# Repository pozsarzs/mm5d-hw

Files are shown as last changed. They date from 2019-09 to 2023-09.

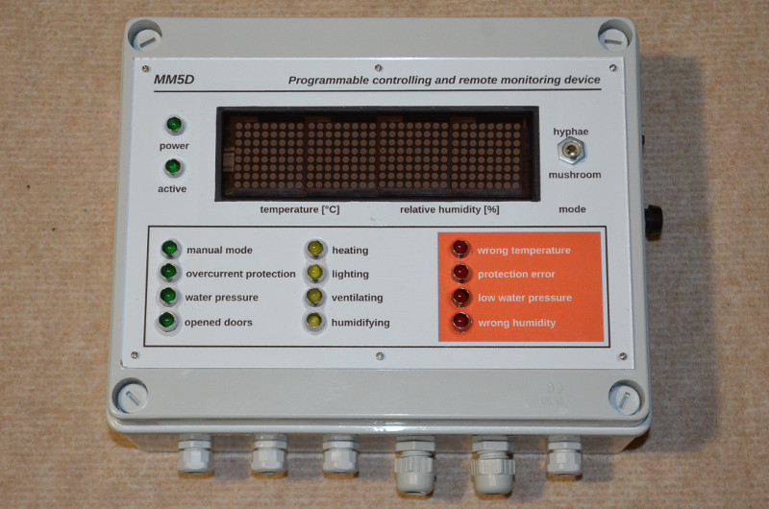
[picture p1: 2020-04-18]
pictures/mm5d.jpg

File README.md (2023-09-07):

**MM5D * Growing house controlling and remote monitoring device**  
Copyright (C) 2019-2020 Pozsár Zsolt <pozsarzs@gmail.com>  
Homepage: <http://www.pozsarzs.hu>  
GitHub: <https://github.com/pozsarzs/mm5d-hw>

**Documentation**

- version:             4.0
- language:            en, hu
- licence:             CC-BY-NC-4.0

**Hardware**

 - version:            v191101

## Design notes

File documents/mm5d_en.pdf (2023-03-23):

## MM5D growing house controlling and remote monitoring unit

### Technical manual

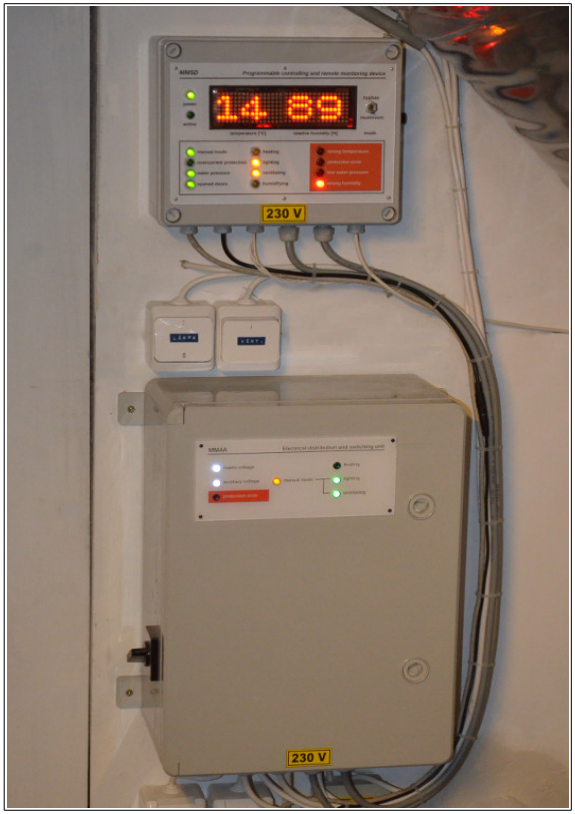
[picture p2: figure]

Hardware version: v191101
Software version: v0.6
Technical manual version: v4.0 Issue date: 2023. 03. 23.
Draw number: 59/5/1-1

## CC-BY-NC-4.0

Content

Titles: | MM5D growing house controlling and remote monitoring unit Rev.: 191101 Pages: | 2/34
Technical manual
Name: Pozsár Zsolt | Date: 2023. 03. 23.

## I. Hardware

Titles: | MM5D growing house controlling and remote monitoring unit Rev.: 191101 Pages: | 3/34

The device - cooperates with MM4A distribution and switching unit - is capable of measuring, controlling and monitoring the characteristics of a growing site.

### 1. Technical data

Supply voltage: | 5V DC (with 230 V AC/5 V DC power supply)
Supply current: | max. 2.5 A
Isolation class: | Class I
Mechanical size: | 240 x 190 x 90 mm
IP protection: | IP 54
Mass of cover: | termoplast (ABS)
Communication: | Ethernet (RJ45),
| Wireless LAN,
| TTL 3.3V serial port
Administration: | SSH,
| serial console
Input:
sign | function | note
IN 1 | MM4A manual operation mode | manual mode: level L
IN 2 | MM4A overcurrent error | error: level L
IN 3 | check water pressure | good: level L
IN 4 | check state of doors | closed: level L

Outputs:
sign | function | note
OUT 1 | heater control output to MM4A
OUT 2 | lighting control output to MM4A
OUT 3 | ventilator control output to MM4A
OUT 4 | humidifier control output

Error sign lamps:
sign | function | note
ERR 1 | temperature is out of good range
ERR 2 | MM4A overcurrent error
ERR 3 | water pressure is too low
ERR 4 | humidity is out of good range
Titles: | MM5D growing house controlling and remote monitoring unit Rev.: 191101 Pages: | 4/34

Status outputs:
sign | function | note
OUT 5 | signal tower light - green | normal operation
OUT 6 | signal tower light - yellow | normal operation with warning
OUT 7 | signal tower light - red | error
OUT 8 | not used/spare

Measured characteristics:
name | range | resolution | accuracy | note
temperature | -40...+80 °C | 0,1 °C | < ±0,5 °C
humidity | 0-100% RH | 0,1 % RH | ±2 % RH

### 2. General description

The device is based on a Raspberry Pi 3 B + microcomputer with Raspbian operating system and includes software needed to operate the unit. Your computer does not have a graphics system installed.

You do not need to connect a keyboard and monitor to set up and operate the device., you can see input and output status, error indications, measured values and system messages (see 3.) on the LEDs and the matrix LED display. You can acces to set up device via local area network with SSH or serial console. The measured data can be checked with a web browser.

The inputs are TTL level inputs with pull-up resistance and the active state is level "L". The inputs are protected against overvoltage and reverse polarity input voltage.

DHT 11, DHT 22 or AM2302 T / RH sensors can be connected to the unit.

The device has eight switching relay contact outputs with a load capacity of up to 250 V AC or up to 30 V DC 10 A, but an external relay or contactor is recommended to protect the printed circuit. Consumer circuits must always be provided with overcurrent protection. The relays can be disabled with the key switch on the right.

### 3. System messages on display

In addition to the measured values, the system may display system messages consisting of the following combination of letters and numbers:

Titles: | MM5D growing house controlling and remote monitoring unit Rev.: 191101 Pages: | 5/34

a) Debug codes

You can see these on display if verbose debug logging enabled.
D #00 | Configuration is loaded.
D #01 | Environment characteristics is loaded.
D #02 | Starting program as daemon.
D #03 | Initializing GPIO ports.
D #04 | Checking override file.
D #05 | Get external temperature from internet.
D #06 | Measuring T/RH.
D #07 | Measure is done.
D #08 | Reading input ports.
D #09 | Check values and set outputs.
D #10 | Writing output ports.
D #11 | Auto off enabled at 4th output port.
D #12 | Creating lockfile.
D #13 | Writing data to log.
D #14 | Removing lockfile.
D #15 | Waiting 10 s.
b) Warning codes
W #01 | Cannot get external temperature from internet.
W #02 | Measured values are bad!
W #51 | MM4A in manual operation mode.
W #52 | Doors/windows are opened.
c) Error codes
E #01 | Cannot open main configuration file.
E #02 | Cannot open environment characteristic configuration file.
E #03 | Cannot create/remove lockfile.
E #04 | Cannot write logfile.
E #51 | Temperature in growing house is out of range.
E #52 | MM4A overcurrent protection error.
E #53 | Water pressure is too low.
E #54 | Relative humidity in growing house is out of range.
Titles: | MM5D growing house controlling and remote monitoring unit Rev.: 191101 Pages: | 6/34

### 4. Signal tower light states

green | normal operation
green+yellow | MM4A is in manual operation mode
one of the doors is open

red

MM4A overcurrent error
water pressure is too low

### 5. Schematic and PCB draws

The wiring diagrams of the device is shown in Annex 1-3, PCB draws are in Annex 5-10. You can download it as part of the complete documentation or in separate PDF, SVG and KiCAD formats from the developer/manufacturer's website. The Gerber files needed for production are included in the package.

### 6. Other draws and documents

Documentation package contents Drilling draws in PDF and DXF format and draw and frontpage in EMF, EPS, PDF, ODG and SVG format and wiring lists in TXT format.

### 7. Terms of use

Hardware documentation can be modified and/or redistributed under the Creativ Commons 4.0 Attribution Non-Commercial (CC-BY-NC-4.0) License. You can read the full (English) text of the license online. (Refer to Chapter III for references.)

### 8. Look of unit

a) Manuals and connectors
1. under supply voltage (green LED)
2. ACT signal light (green LED)
3. matrix display
4. operation mode switch
5. IN 1-4 active input signal light (green LED)
6. OUT 1-4 active output signal light (yellow LED)
7. ERR 1-4 signal light (red LED)
8. console connector (J2)
9. fuse of supply voltage (2,5 A F)
10. disable output relays key switch
Titles: | MM5D growing house controlling and remote monitoring unit Rev.: 191101 Pages: | 7/34

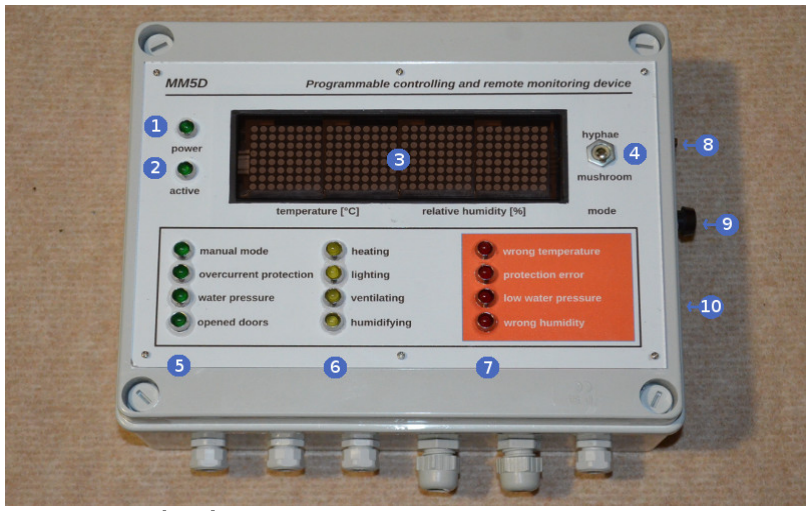
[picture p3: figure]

b) Internal construction
1. Raspberry Pi (U1)
2. GPIO port expansion module (U2)
3. matrix display module (U3)
4. module of LEDs (U4)
5. input module (U5)
6. output module (U6)
7. output module (U7)
8. supply voltage filter and speaker driver circuit
9. speaker
10. power voltage connector (J1)
11. inputs connector (J501)
12. sensor connector (J502)
13. OUT 1-4 connector
14. OUT 5-8 connector
15. screw hole
Titles: | MM5D growing house controlling and remote monitoring unit Rev.: 191101 Pages: | 8/34

Figure 1: Manuals and connectors

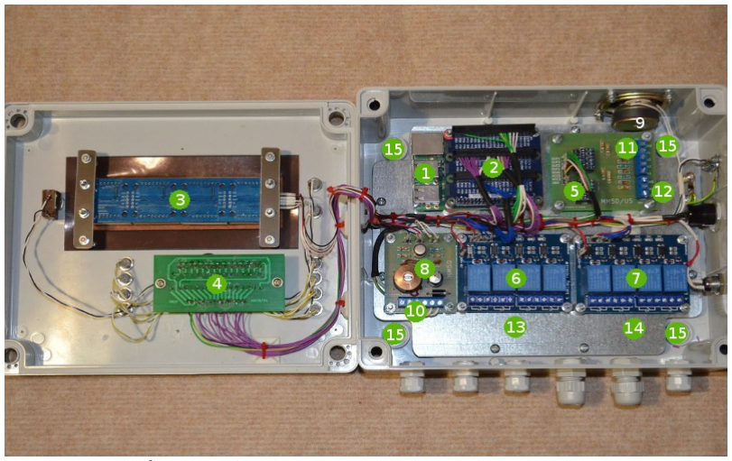
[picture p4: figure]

c) Pinout of connectors
module | connector | pin | function | note
- J1 | | 1 | + 5 V supply voltage input | screw terminal
| | 2 | GND
| | 3 | PE
- J2 | | 2 | serial port RXD | DB9F
| | 3 | serial port TXD
| | 5 | GND
| | 9 | level shifter supply voltage +5 V
U5 | U501 | 1 | input IN 1 | screw terminal
| | 2 | input IN 2
| | 3 | input IN 3
| | 4 | input IN 4
| | 5 | GND
U5 | U502 | 1 | sensor supply voltage +5 V | screw terminal
| | 2 | communication with sensor
| | 3 | GND
Titles: | MM5D growing house controlling and remote monitoring unit Rev.: 191101 Pages: | 9/34

Figure 2: Internal construction

module | connector | pin | function | note
U6 | K4-K3 | 1 | output OUT 4 NO contact | screw terminal
| | 2 | output OUT 4 COM contact
| | 3 | output OUT 4 NC contact
| | 4 | output OUT 3 NO contact
| | 5 | output OUT 3 COM contact
| | 6 | output OUT 3 NC contact
U6 | K2-K1 | 1 | output OUT 2 NO contact | screw terminal
| | 2 | output OUT 2 COM contact
| | 3 | output OUT 2 NC contact
| | 4 | output OUT 1 NO contact
| | 5 | output OUT 1 COM contact
| | 6 | output OUT 1 NC contact
U7 | K4-K3 | 1 | output OUT 8 NO contact | screw terminal
| | 2 | output OUT 8 COM contact
| | 3 | output OUT 8 NC contact
| | 4 | output OUT 7 NO contact
| | 5 | output OUT 7 COM contact
| | 6 | output OUT 7 NC contact
U7 | K2-K1 | 1 | output OUT 6 NO contact | screw terminal
| | 2 | output OUT 6 COM contact
| | 3 | output OUT 6 NC contact
4 | output OUT 5 NO contact
5 | output OUT 5 COM contact
6 | output OUT 5 NC contact

The numbering is from left to right, from bottom to top at the input module.

Titles: | MM5D growing house controlling and remote monitoring unit Rev.: 191101 Pages: | 10/34

### 9. Downloadable documentation

The complete documentation of the hardware in the .tar.gz format compressed file can be downloaded from the manufacturer's website or Github. (Refer to Chapter III for references.) Name of package is: mm5d-hw-191101-4.0.tar.gz. Content of package - only important files:

mm5d-hw
├───cad_files | KiCAD and LibreCAD files
│ | ├───connecting | example of application
│ | │ | connecting.pro | project file
│ | │ | connecting.sch | schematic draw
│ | ├───drilling | drilling draws
│ | │ | bottom.dxf | bottom side of box
│ | │ | front.dxf | front of box
│ | │ | mountingplate.dxf | mounting plate
│ | │ | rightside.dxf | right side of box
│ | │ | top.dxf | top side of box
│ | ├───mm5d-sch | schematic draws
│ | │ | mm5d.pro | project file
│ | │ | mm5d.sch | schematic draw
│ | │ | u4.sch | module U4 schematic draw
│ | │ | u5.sch | module U5 schematic draw
│ | ├───mm5d-pcb | pcb draw
│ | │ | mm5d.pro | project file
│ | │ | mm5d.kicad_pcb | PCB draw
│ | │ | mm5d.drl | drilling file
│ | │ | mm5d-*.gbr | Gerber files
│ | ├───mm5d-u4-pcb | module U4 PCB draw
│ | │ | u4.pro | project file
│ | │ | u4.kicad_pcb | PCB draw
│ | │ | u4.drl | drilling file
│ | │ | u4-*.gbr | Gerber files
│ | └───mm5d-u5-pcb | module U5 PCB draw
│ | | u5.pro | project file
│ | | u5.kicad_pcb | PCB draw
│ | | u5.drl | drilling file
│ | | u5-*.gbr | Gerber files
├───documents | documentation
│ | | mm5d_en.pdf | Technical manual
│ | drill_*.pdf | drilling draws of box
│ | pcb_mm5d-*.pdf | pcb draws
│ | sch_mm5d-*.pdf | schematic draws
├───frontpage | frontpage
│ | | frontpage.emf | frontpage draw
│ | | frontpage.odg | frontpage draw
│ | mirrored_frontpage.eps | mirrored frontpage draw
│ | mirrored_frontpage.pdf | mirrored frontpage draw
│ | mirrored_frontpage.svg | mirrored frontpage draw
├───pictures | pictures
│ | | mm5d.jpg | look of the unit
│ | pcb_mm5d-*.svg | PCB draws
│ | sch_mm5d-*.svg | schematic draws
├───wiring | wiring
│ | | gpio-jp*.txt | wiring lists
│
├───LICENCE | terms of use
└───README.md | short description
Titles: | MM5D growing house controlling and remote monitoring unit Rev.: 191101 Pages: | 11/34

## II. Software

Titles: | MM5D growing house controlling and remote monitoring unit Rev.: 191101 Pages: | 12/34

### 1. General description

The software consists of five main parts:

Operating daemon

Measurement, timing and electrical equipment control is done by a Python-language program that runs as a service in the background. Its utilities are Bash shell programs, the configuration files are in text (INI) format. The setup program has a full screen character interface, its source code (FreePascal) is included in the tar.gz package only. This part of the software is included in the tar.gz package and the mm5d-sw_0.6-1_armhf.deb package.

Matrix display handler daemon

The LED matrix display is handled by a Python-language program that runs as a service in the background. It communicates with the previous service through a named pipe file. This part of the software is included in the tar.gz package and the mm5d-sw_0.6-1_armhf.deb package.

Environmental characteristics adjustment program

The setup program has a full screen character interface, its source code (FreePascal) is included in the tar.gz package only. This part of the software is included in the tar.gz package and the mm5d-eec_0.6-1_armhf.deb package.

Web interface

Data access is provided by CGI programs written in Perl, its Bash shell utility, and web content consists of static HTML files. Currently available in English, Czech, French, Croatian, Polish, Hungarian, German, Russian, Romanian, Serbian, Slovak, Slovenian and Ukrainian. This requires an Apache2 web server. This part of the software is included in the tar.gz package and the mm5d-web_0.6-1_all.deb package.

Hardware checker program

This Python program can be used to verify that the hardware is working properly. During the test, general information and messages are displayed on the screen, test information is displayed on the matrix display. Before testing, both running services of the software must be stopped. This part of the software is included in the tar.gz package and the mm5d-sw_0.6-1_armhf.deb package.

Titles: | MM5D growing house controlling and remote monitoring unit Rev.: 191101 Pages: | 13/34

### 2. Prepare installation

Before installing the program, you need to install Raspbian OS Lite on your Raspberry Pi. Remember to change the default password for pi, set the device name (hostname) and access to the local network. For easy remote access, use a permanent IP address or set up an IP address assignment on your router.

Prepare operation system:

pi@raspberry$ sudo apt-get update
pi@raspberry$ sudo apt-get upgrade
pi@raspberry$ sudo apt-get install git wget
pi@raspberry$ sudo echo "deb http://www.szerafingomba.hu/deb/ ./" >> /etc/apt/sources.list
pi@raspberry$ sudo wget -q -O - http://www.szerafingomba.hu/deb/KEY.gpg | apt-key add -
pi@raspberry$ sudo apt-get update
pi@raspberry$ mkdir $HOME/download

### 3. Download

Download program from homepage:

pi@raspberry$ cd $HOME/download
pi@raspberry$ wget http://www.szerafingomba.hu/softwares/mm5d/mm5d-sw-0.5-armhf.tar.gz pi@raspberry$ tar -xzf mm5d-sw-0.5-armhf.tar.gz

Download latest version of program from Github:

pi@raspberry$ cd $HOME/download
pi@raspberry$ git clone https://github.com/pozsarzs/mm5d-sw.git

### 4. Installation

pi@raspberry$ cd mm5d-sw
pi@raspberry$ ./prepare
pi@raspberry$ ./install

Download and install with package manager:

pi@raspberry$ sudo apt-get install mm5d-prepare pi@raspberry$ mm5d-prepare
pi@raspberry$ sudo apt-get install mm5d-sw mm5d-web mm5d-eec

### 5. Files of program

The program's installed and | created on runtime | files, with explanations of important files for
the user and the purpose of symbolic links:

/
│
├───etc
Titles: | MM5D growing house controlling and remote monitoring unit Rev.: 191101 Pages: | 14/34

│ | ├───cron.d
│ | │ | mm5d
│ | ├───init.d
│ | │ | matrixdisplay.sh
│ | │ | mm5d.sh
│ | ├───rc0.d
│ | │ | K01mm5d.sh | » /etc/init.d/mm5d.sh
│ | │ | K02matrixdisplay.sh | » /etc/init.d/matrixdisplay.sh
│ | ├───rc2.d
│ | │ | S01mm5d.sh | » /etc/init.d/mm5d.sh
│ | │ | S02matrixdisplay.sh | » /etc/init.d/matrixdisplay.sh
│ | ├───rc3.d
│ | │ | S01mm5d.sh | » /etc/init.d/mm5d.sh
│ | │ | S02matrixdisplay.sh | » /etc/init.d/matrixdisplay.sh
│ | ├───rc4.d
│ | │ | S01mm5d.sh | » /etc/init.d/mm5d.sh
│ | │ | S02matrixdisplay.sh | » /etc/init.d/matrixdisplay.sh
│ | ├───rc5.d
│ | │ | S01mm5d.sh | » /etc/init.d/mm5d.sh
│ | │ | S02matrixdisplay.sh | » /etc/init.d/matrixdisplay.sh
│ | ├───rc6.d
│ | │ | K01mm5d.sh | » /etc/init.d/mm5d.sh
│ | │ | K02matrixdisplay.sh | » /etc/init.d/matrixdisplay.sh
│ | ├───systemd
│ | │ | └───system
│ | │ | matrixdisplay.service
│ | │ | mm5d.service
│ | └───motd
├───usr
│ | ├───lib
│ | │ | └───cgi
│ | │ | getdata.cgi
│ | │ | getenvirconf.cgi
│ | │ | getpage.cgi
│ | └───local
│ | ├───bin
│ | │ | matrixdisplay.py | daemon program
│ | │ | mm5d.py | daemon program
│ | │ | mm5d-creatediagrams | diagram creator
│ | │ | mm5d-editenvirconf | edit envir. characteristics
│ | │ | mm5d-editenvirconf.bin | settings editor
│ | │ | mm5d-editmainconf | edit program settings
│ | │ | mm5d-editmainconf.bin | settings editor
│ | │ | mm5d-getsnapshots | camera picture downloader
│ | │ | mm5d-hwtest.py | hardware checker
│ | │ | mm5d-maintainlog | maintain log
│ | │ | mm5d-override | override outputs
│ | │ | mm5d-override.bin | settings editor
│ | │ | mm5d-startdaemon | start daemons
│ | │ | mm5d-statusofdaemon | view status of daemon
│ | │ | mm5d-stopdaemon | stop daemons
│ | │ | mm5d-updatestartpage | update first webpage
│ | │ | mm5d-viewlog | show logfile
│ | │ | mm5d-webpage | view own webpage
│ | ├───etc
│ | │ | └───mm5d
│ | │ | mm5d.ini | envir. characteristics settings
│ | │ | envir.ini | program settings
│ | └───share
│ | ├───doc
│ | │ | └───mm5d
│ | │ | AUTHORS | author(s)
Titles: | MM5D growing house controlling and remote monitoring unit Rev.: 191101 Pages: | 15/34

│ | │ | ChangeLog | change log
│ | │ | copyright | copyright information
│ | │ | COPYING | terms of use (EN)
│ | │ | INSTALL | installation instruction (EN)
│ | │ | README | information (EN)
│ | │ | VERSION | version
│ | │ | debug_codes.txt | debug codes
│ | │ | error_codes.txt | error codes
│ | │ | gpioports.txt | used GPIO ports
│ | │ | variables.txt | used main variables
│ | │ | warning_codes.txt | warning codes
│ | ├───locale
│ | │ | └───??
│ | │ | mm5d.msg
│ | ├───man
│ | │ | └───man1 | manual pages (EN)
│ | │ | getdata.cgi.7.gz
│ | │ | getenvirconf.cgi.7.gz
│ | │ | getpage.cgi.7.gz
│ | │ | matrixdisplay.py.8.gz
│ | │ | mm5d.py.8.gz
│ | │ | mm5d-creatediagrams.1.gz
│ | │ | mm5d-editenvirconf.1.gz
│ | │ | mm5d-editmainconf.1.gz
│ | │ | mm5d-getsnapshots.1.gz
│ | │ | mm5d-hwtest.py.1.gz
│ | │ | mm5d-maintainlog.1.gz
│ | │ | mm5d-override.1.gz
│ | │ | mm5d-startdaemon.1.gz
│ | │ | mm5d-statusofdaemon.1.gz
│ | │ | mm5d-stopdaemon.1.gz
│ | │ | mm5d-updatestartpage.1.gz
│ | │ | mm5d-viewlog.1.gz
│ | │ | mm5d-webpage.1.gz
│ | └───mm5d
│ | footer_??.html
│ | header_??.html
└───var
├───local
│ | ├───lib
│ | │ | out1
│ | │ | out2
│ | │ | out3
│ | │ | out4
│ | ├───lock
│ | │ | mm5d.lock
│ | │
│ | └───log
│ | mm5d.bak
│ | mm5d.log
│ | debug-*.log | debug log
├───run
│ mm5d.pid
├───tmp
│ | matrixdisplayfifo | FIFO file (named pipe)
└───www
└───html
├───pics
│ | ants.jpg
│ | camera1.jpg
│ | camera2.jpg
Titles: | MM5D growing house controlling and remote monitoring unit Rev.: 191101 Pages: | 16/34

│ | dark.png
│ | green.png
│ | humidity.png
│ | mm5d-creatediagrams.tmp
│ | red.png
│ | szerafin.ico
│ | temperature.png
│ | yellow.png
styles.css
index.html
szerafin.ico
When installing with package manager, the program is installed to /usr instead of /usr/local.

### 6. Setup

To set the program:

mm5d@raspberry$ mm5d-editmainconf

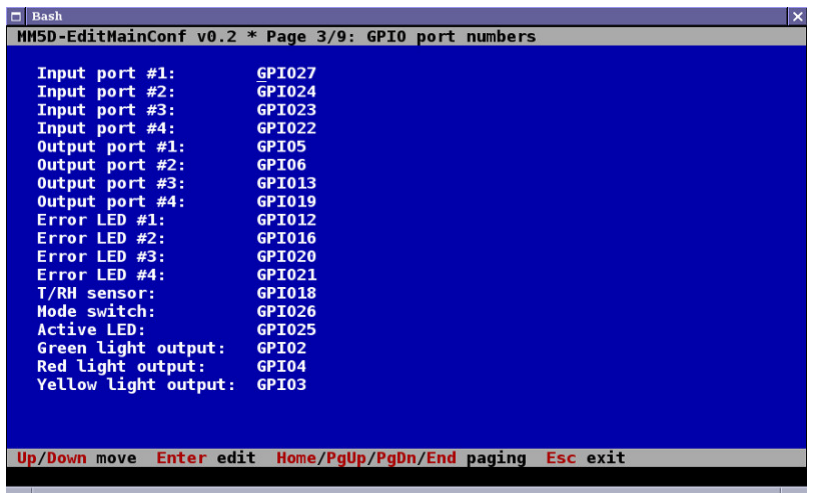
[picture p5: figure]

To set the environmental characteristics:

mm5d@raspberry$ mm5d-editenvirconf

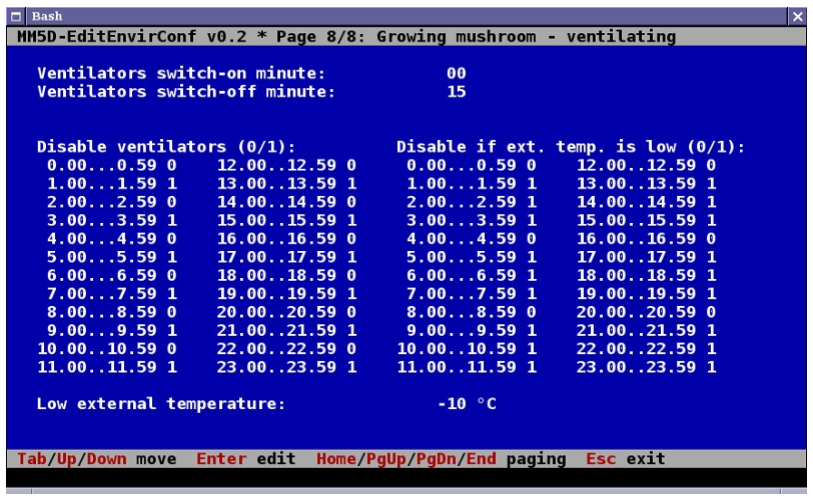
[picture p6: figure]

Titles: | MM5D growing house controlling and remote monitoring unit Rev.: 191101 Pages: | 17/34

Figure 3: mm5d-editmainconf

Figure 4: mm5d-editenvirconf

### 7. Using the device

The device works automatically after installation and does not require human intervention. Checking and configuring your operation is only possible remotely via a network.

The device can be configured via SSH or serial console, the environmental characteristics can be set via SSH, serial console or with XMMEEC program. In the third case, a key-based login is required.

The set environment characteristic, the current status and the measured data can be checked with a web browser or MM5DRead program. Many data can be queried over HTTP without a browser. See getdata.cgi.7.gz manual page for details.

Login via serial port

The console connector of the device and the RS-232 serial port of the computer must be connected by means of a level shifter adapter with a null modem cable. The level shifter adapter is required due to the different voltages of the logic levels (0 V / 3.3 V and -12 V / + 12 V). The console connector of the device and the USB port of the computer must be connected using an Adafruit 954, FTDI TTL-232R-RPI or similar 3.3V serial / USB cable.

Connection parameters
speed (baudrate): | 115 200 bps
data bits: | 8
parity bit: | no
stop bit: | 1
flow control: | no

Connect via linux terminal

Name of ports (device files):
RS-232 serial port: | /dev/ttyS0, /dev/ttyS1, ...
serial/USB converter: | /dev/ttyUSB0, /dev/ttyUSB1, ...
Make sure you are a member of the dialout group:

username@localhost$ id
If not, set up your group membership:

username@localhost$ sudo usermod -a -G dialout username
Connect with GNU Screen or Minicom program:

username@localhost$ screen port_name 115200 username@localhost$ minicom -b 115200 -o -D port_name

Titles: | MM5D growing house controlling and remote monitoring unit Rev.: 191101 Pages: | 18/34

### 8. Terms of use

This program is free software: you can redistribute it and/or modify it under the terms of the European Union Public License 1.1 version.

This program is distributed in the hope that it will be useful, but WITHOUT ANY WARRANTY; without even the implied warranty of MERCHANTABILITY or FITNESS FOR A PARTICULAR PURPOSE.

You can read the full text of the license online. (Refer to Chapter III for references.)

### 9. Downloadable software package

The package can be downloaded from the manufacturer's website in a .tar.gz compressed file. (Refer to Chapter III for references.) Name of current package: mm5d-sw-0.6-armhf.tar.gz

Content of this package (only directories and important files for users):

mm5d-sw
│
├───binary | binary files
│
├───documents | documentation
│
├───manuals | manual pages
│
├───messages | translated webpage text
│
├───packaging | files for make deb packages
│
├───programs | main programs (Python)
│
├───scripts | utility programs (Bash)
│
├───settings | configuration files
│
├───source | source code
│
├───webpage | components of webpage
│
├───install | installer script
├───prepare | script for prepare OS
├───uninstall | uninstaller script
├───LICENCE | terms of use
└───README.md | short description
Titles: | MM5D growing house controlling and remote monitoring unit Rev.: 191101 Pages: | 19/34

## III. Related links

Titles: | MM5D growing house controlling and remote monitoring unit Rev.: 191101 Pages: | 20/34

### 1. Hardware

Full documentation | http://www.szerafingomba.hu/equipments/mm5d/mm5d-hw-191101-3.0.tar.gz
Github | https://github.com/pozsarzs/mm5d-hw.git
Technical manual | http://www.szerafingomba.hu/equipments/mm5d/technical-manual-191101-3.0-en.pdf

Schematic drawings (PDF):
MM5D | http://www.szerafingomba.hu/equipments/mm5d/sch_mm5d.pdf
Module U4 | http://www.szerafingomba.hu/equipments/mm5d/sch_mm5d-u4.pdf
Module U5 | http://www.szerafingomba.hu/equipments/mm5d/sch_mm5d-5.pdf
Example of application http://www.szerafingomba.hu/equipments/mm5d/sch_mm5d-connecting.pdf

Printed circuits boards (PDF):
MM5D solder side | http://www.szerafingomba.hu/equipments/mm5d/pcb_mm5d-sold.pdf
MM5D silkscreen | http://www.szerafingomba.hu/equipments/mm5d/pcb_mm5d-silk.pdf
Module U4 solder side http://www.szerafingomba.hu/equipments/mm5d/pcb_mm5d-u4-sold.pdf Module U4 silkscreen http://www.szerafingomba.hu/equipments/mm5d/pcb_mm5d-u4-silk.pdf Module U5 solder side http://www.szerafingomba.hu/equipments/mm5d/pcb_mm5d-u5-sold.pdf Module U5 silkscreen http://www.szerafingomba.hu/equipments/mm5d/pcb_mm5d-u5-silk.pdf

### 2. Software

Software package http://www.szerafingomba.hu/softwares/mm5d/mm5d-sw-0.5-armhf.tar.gz Download from Github https://github.com/pozsarzs/mm5d-sw.git

### 3. Terms of use

CC-BY-NC-4.0 | https://creativecommons.org/licenses/by-nc/4.0/legalcode
CC-BY-NC-4.0 | https://creativecommons.org/licenses/by-nc/4.0/
EUPL v1.2 | https://eupl.eu/1.2/en/

### 4. Developer and manufacturer

Homepage | https://www.szerafingomba.hu
E-mail | info@szerafingomba.hu
Titles: | MM5D growing house controlling and remote monitoring unit Rev.: 191101 Pages: | 21/34

## IV. Annexes

Titles: | MM5D growing house controlling and remote monitoring unit Rev.: 191101 Pages: | 22/34

### 1. Schematic drawings

1. MM5D schematic drawing
2. Module U4 schematic drawing
3. Module U5 schematic drawing
4. Example of application schematic drawing

### 2. Printed circuit boards

5. MM5D solder side
6. MM5D silkscreen
7. Module U4 solder side
8. Module U4 silkscreen
9. Module U5 solder side
10. Module U5 silkscreen
Titles: | MM5D growing house controlling and remote monitoring unit Rev.: 191101 Pages: | 23/34

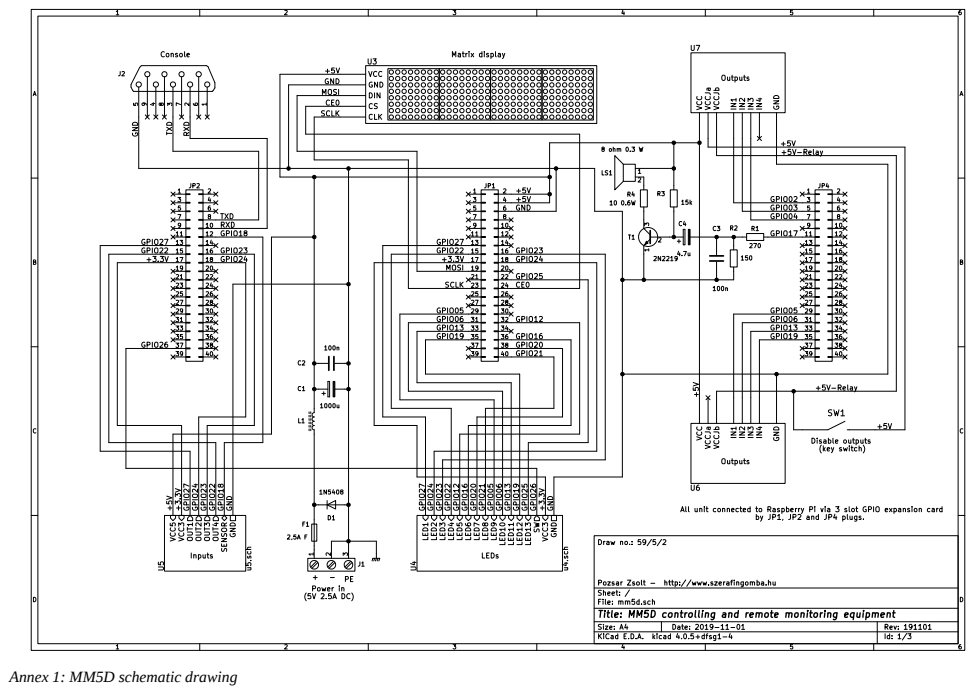
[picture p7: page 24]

Annex 1: MM5D schematic drawing

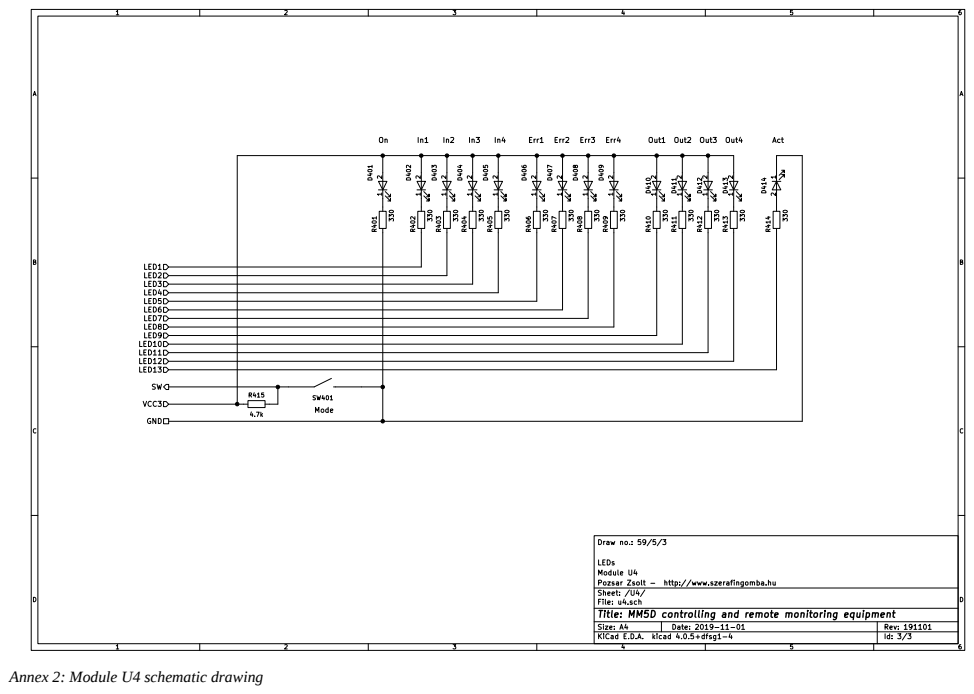
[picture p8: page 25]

Annex 2: Module U4 schematic drawing

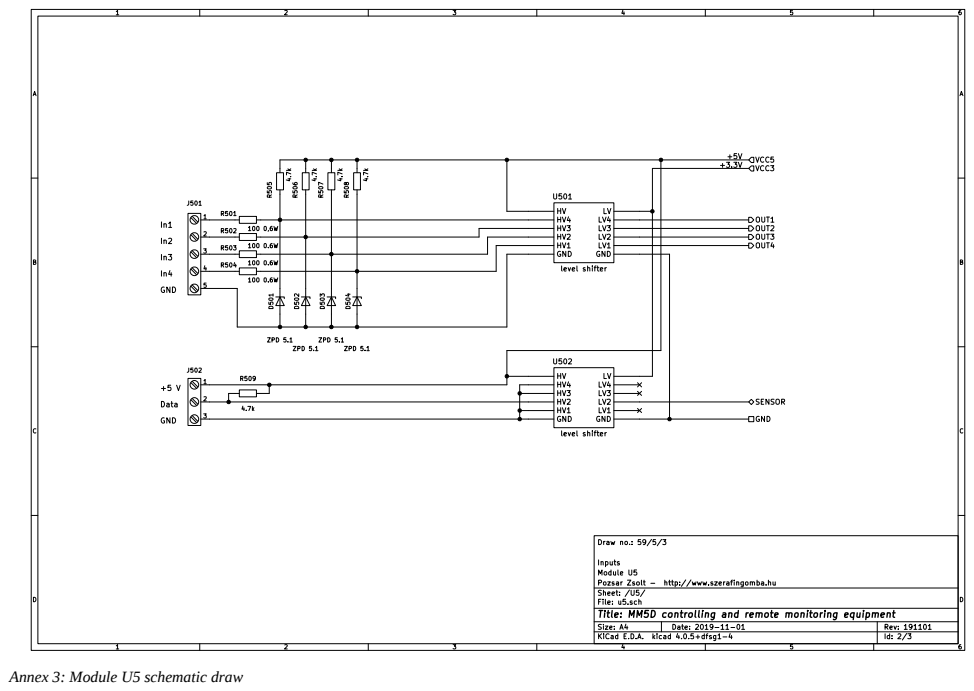
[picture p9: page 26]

Annex 3: Module U5 schematic draw

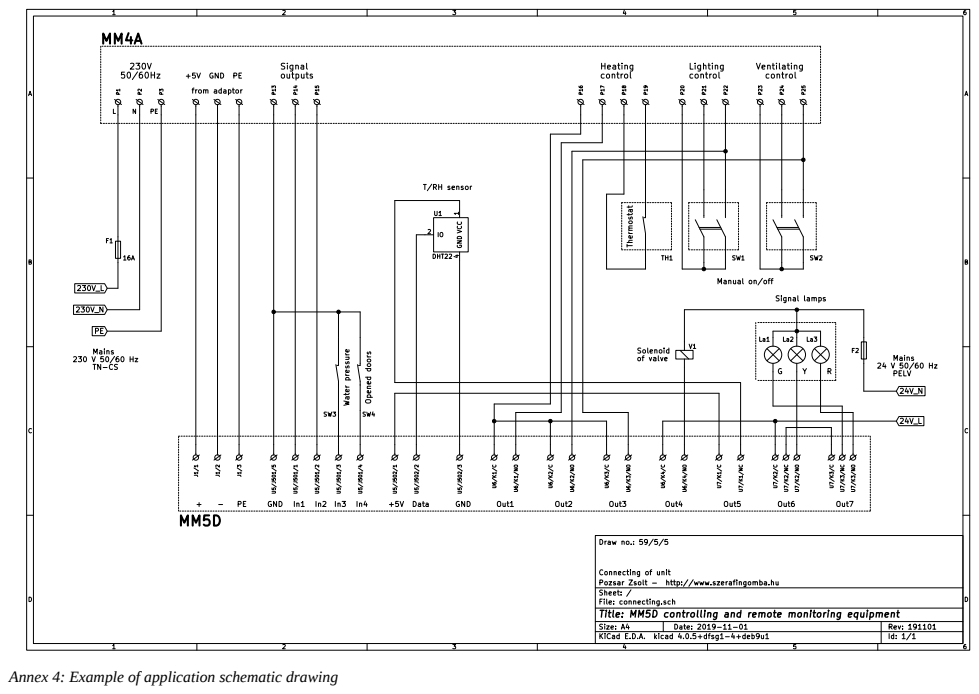
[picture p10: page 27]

Annex 4: Example of application schematic drawing

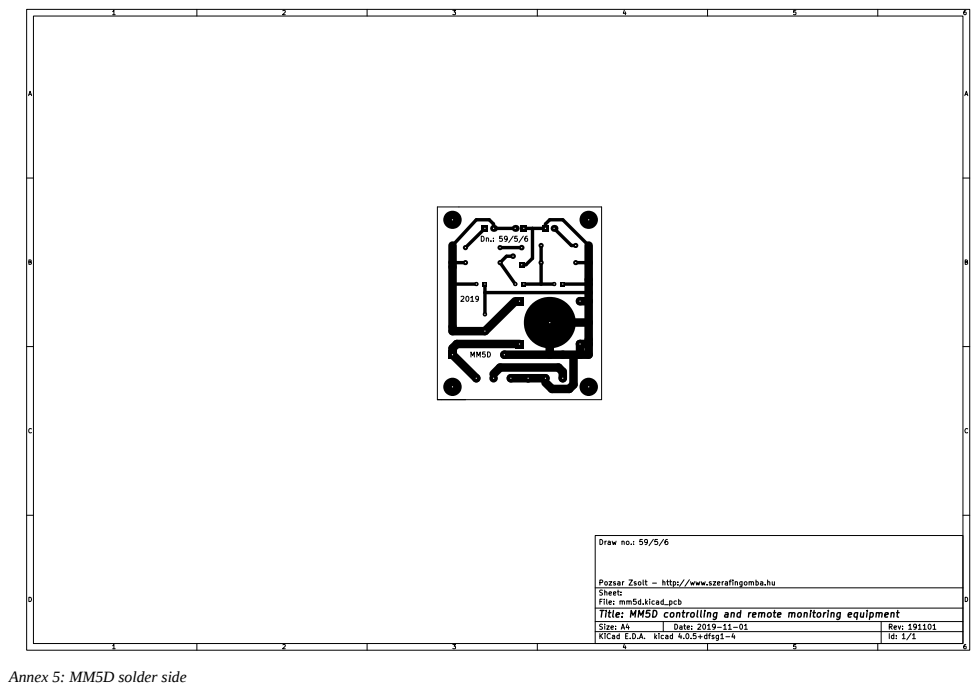
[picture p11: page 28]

Annex 5: MM5D solder side

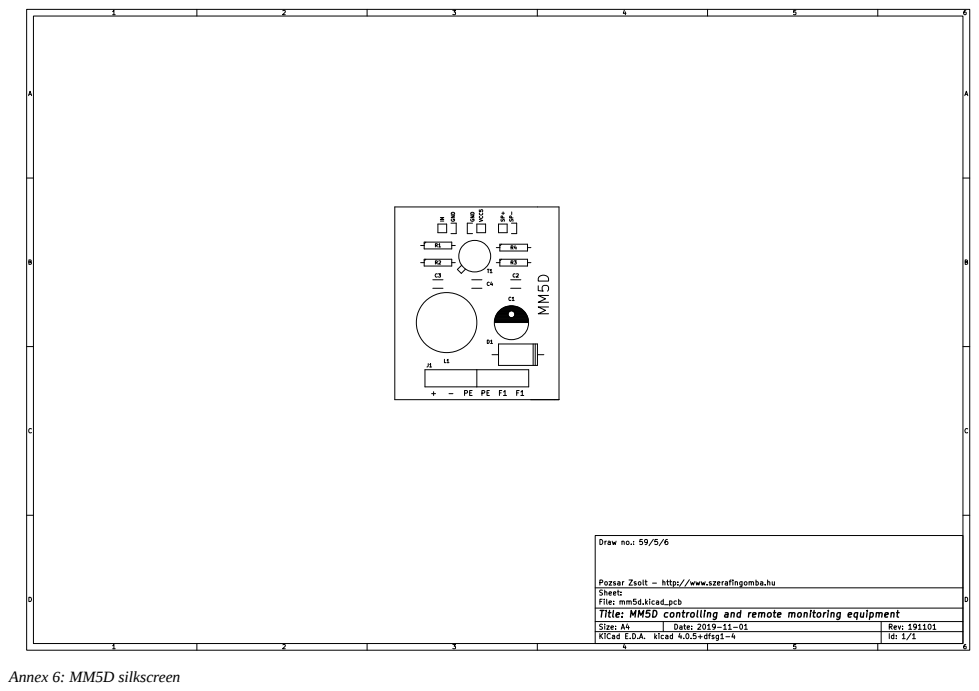
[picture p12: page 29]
Annex 6: MM5D silkscreen

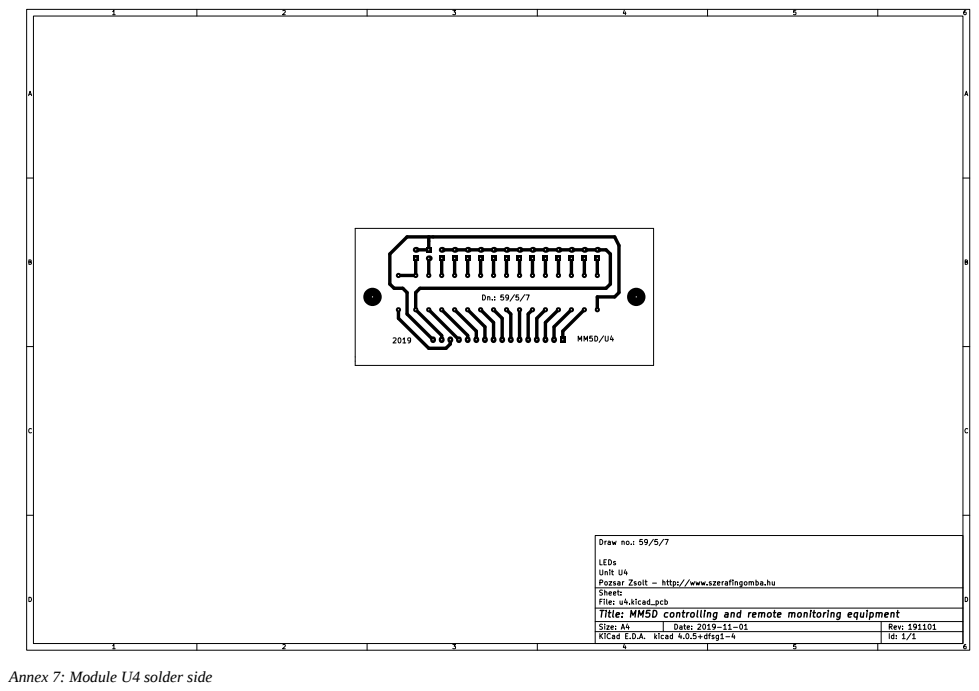
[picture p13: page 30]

Annex 7: Module U4 solder side

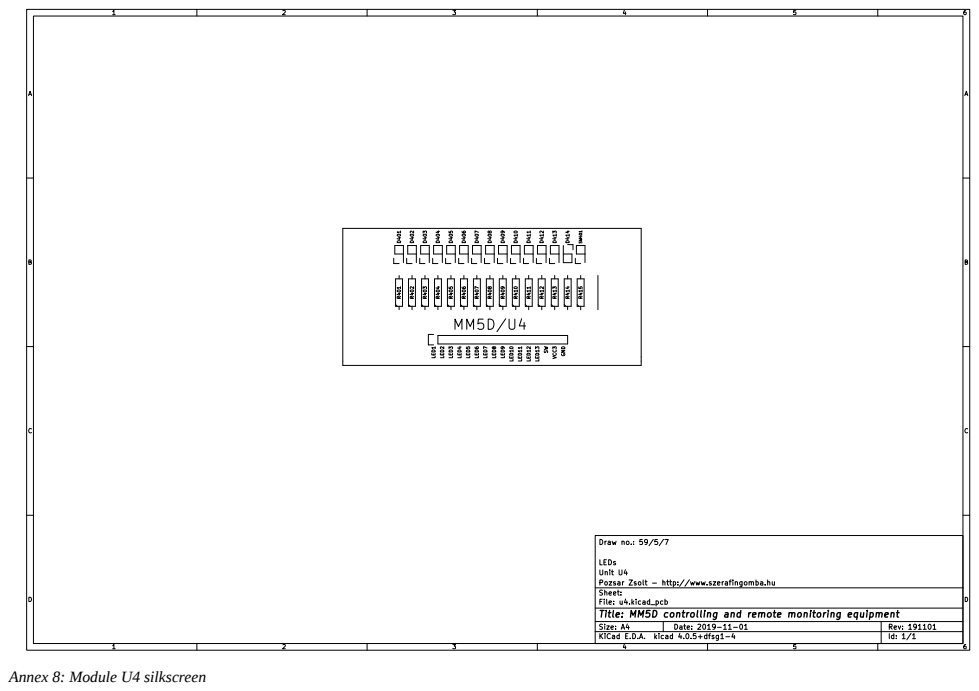
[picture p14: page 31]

Annex 8: Module U4 silkscreen

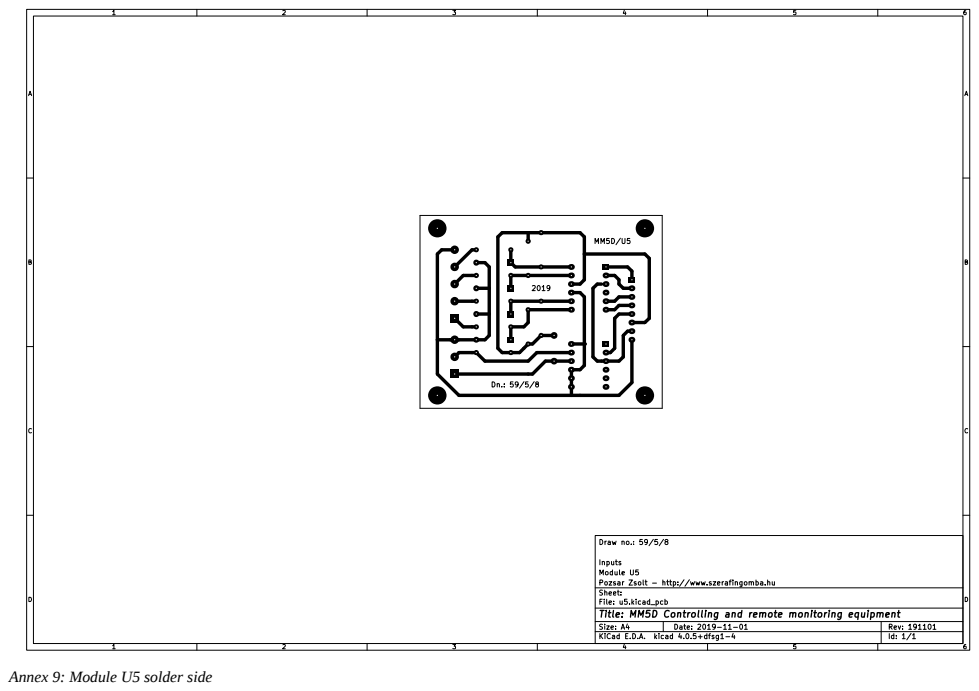
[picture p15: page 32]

Annex 9: Module U5 solder side

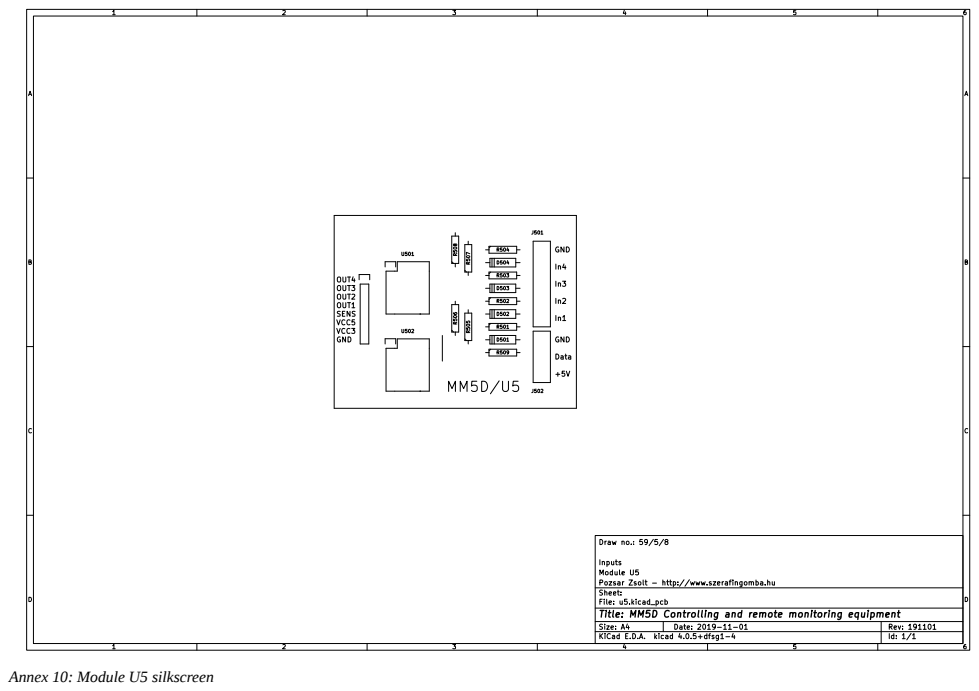
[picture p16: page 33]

Annex 10: Module U5 silkscreen

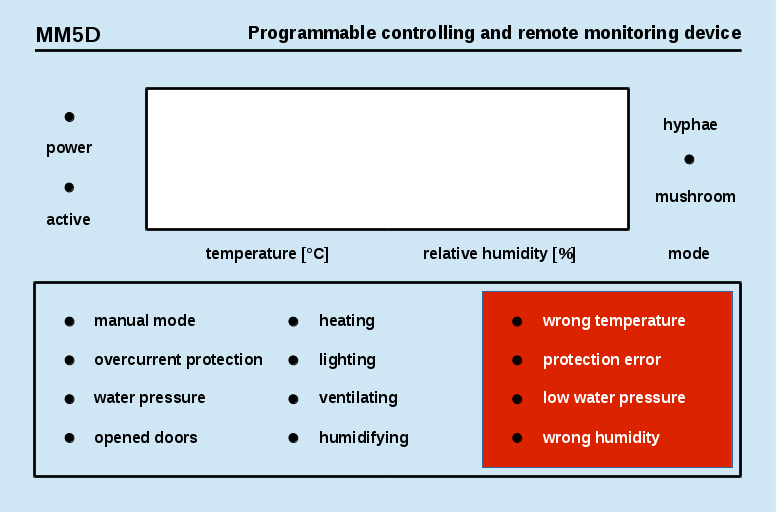
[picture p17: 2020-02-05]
frontpage/preview.png

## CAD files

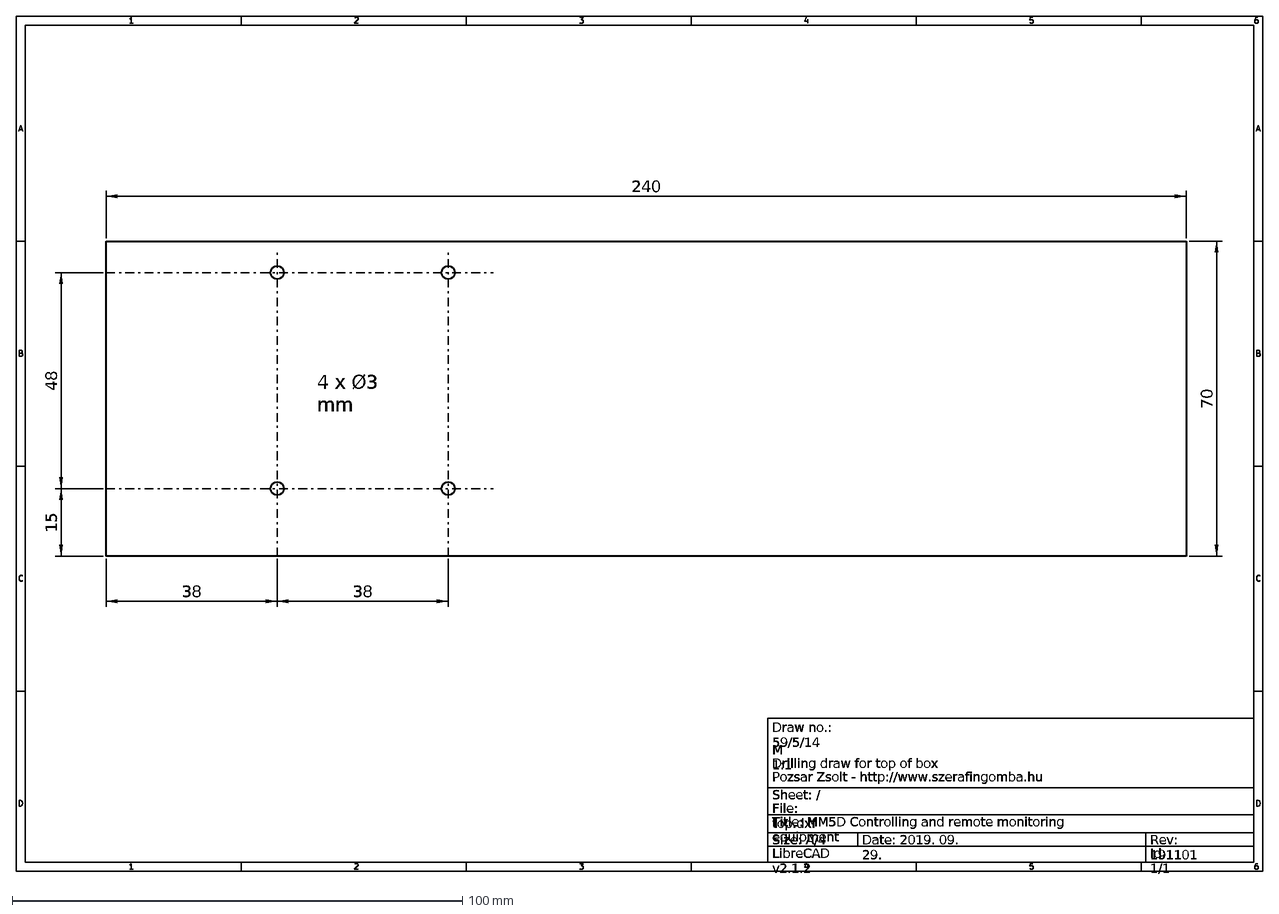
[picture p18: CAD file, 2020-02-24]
cad_files/drilling/top.dxf
240
Size: A/4
LibreCAD v2.1.2
Sheet: /
File: top.dxf
Date: 2019. 09. 29.
Rev: 191101
Id: 1/1
Pozsar Zsolt - http://www.szerafingomba.hu
Title: MM5D Controlling and remote monitoring equipment
Drilling draw for top of box
M 1:1
Draw no.: 59/5/14
15
48
38
70
4 x Ø3 mm

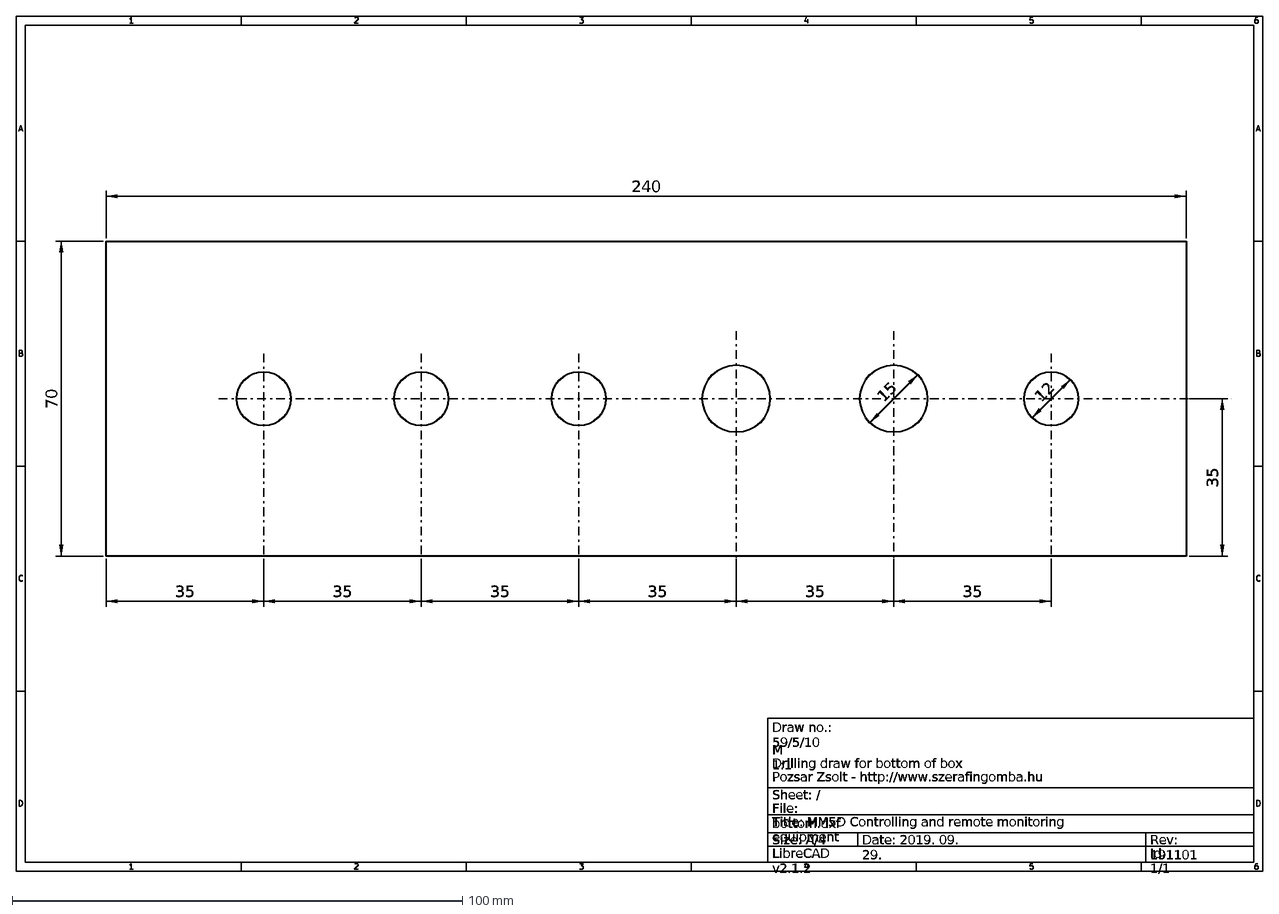
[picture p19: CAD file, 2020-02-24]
cad_files/drilling/bottom.dxf
35
12
15
70
240
Size: A/4
LibreCAD v2.1.2
Sheet: /
File: bottom.dxf
Date: 2019. 09. 29.
Rev: 191101
Id: 1/1
Pozsar Zsolt - http://www.szerafingomba.hu
Title: MM5D Controlling and remote monitoring equipment
Drilling draw for bottom of box
M 1:1
Draw no.: 59/5/10

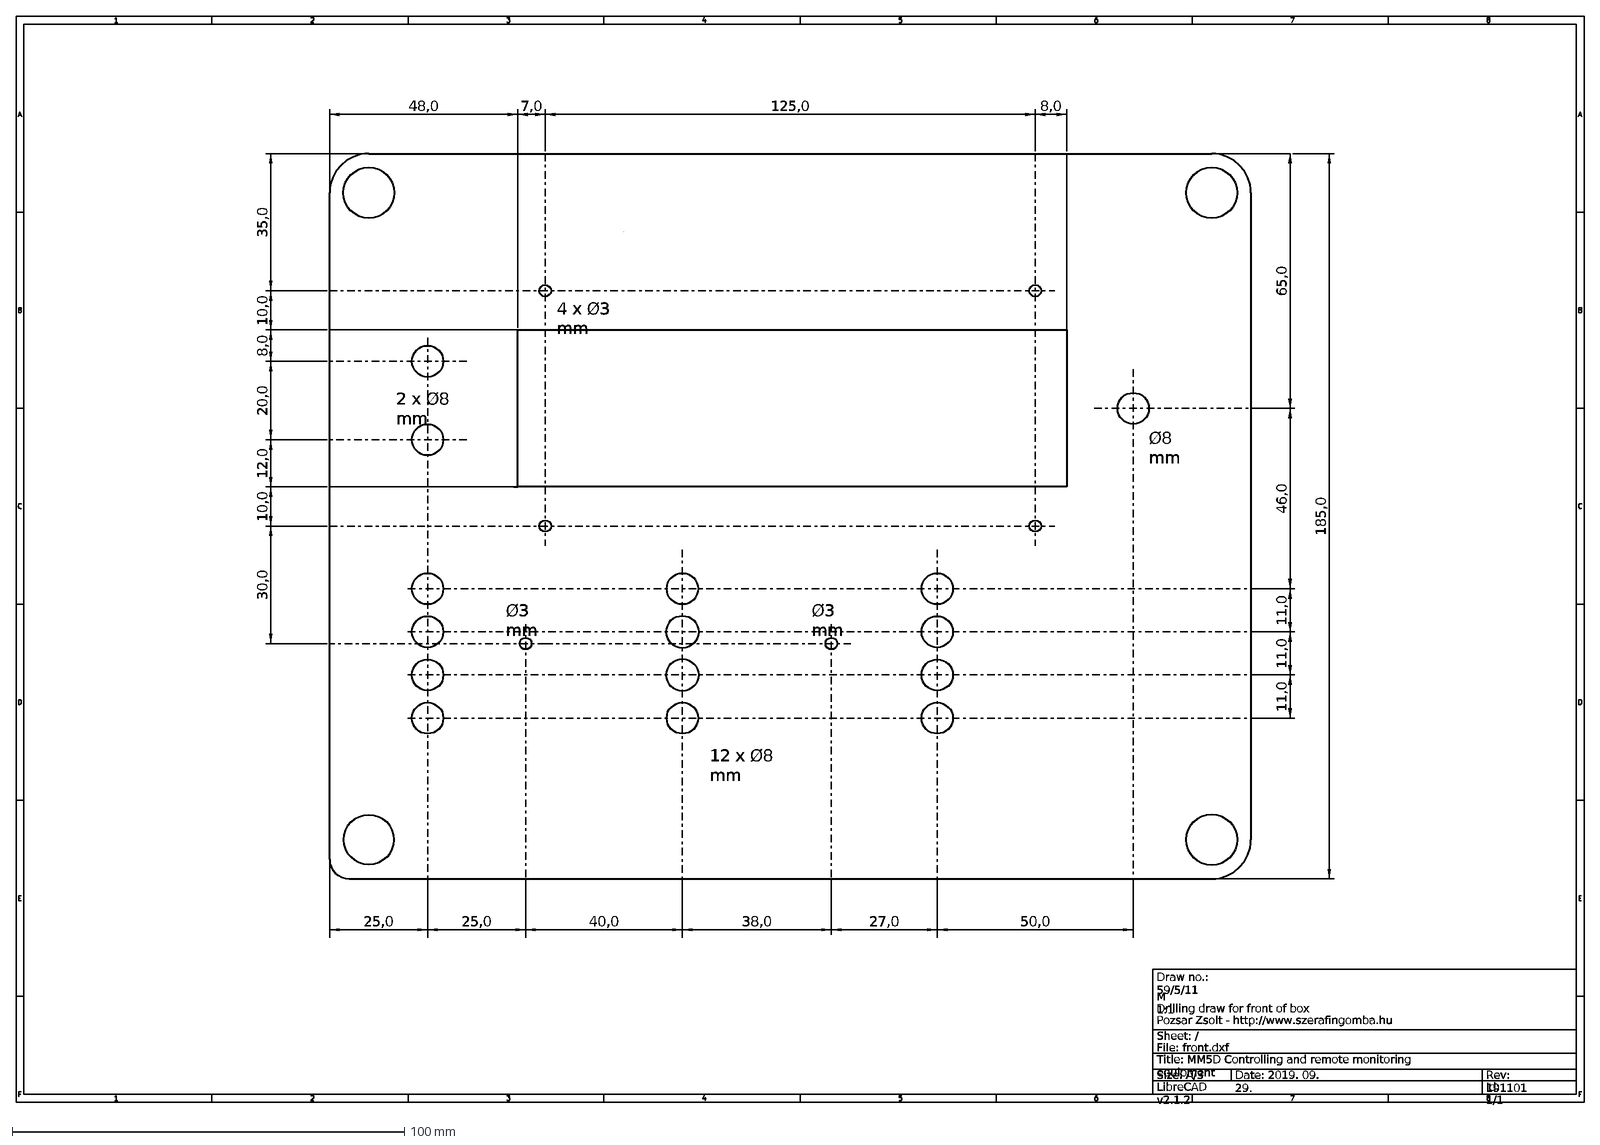
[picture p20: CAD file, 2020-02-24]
cad_files/drilling/front.dxf
LibreCAD v2.1.2
Sheet: /
Date: 2019. 09. 29.
Rev: 191101
Id: 1/1
Pozsar Zsolt - http://www.szerafingomba.hu
Title: MM5D Controlling and remote monitoring equipment
M 1:1
File: front.dxf
Size: A/3
Drilling draw for front of box
Draw no.: 59/5/11
25,0
46,0
11,0
185,0
48,0
27,0
40,0
38,0
50,0
65,0
Ø3 mm
12 x Ø8 mm
2 x Ø8 mm
Ø8 mm
4 x Ø3 mm
35,0
20,0
12,0
10,0
30,0
7,0
125,0
8,0

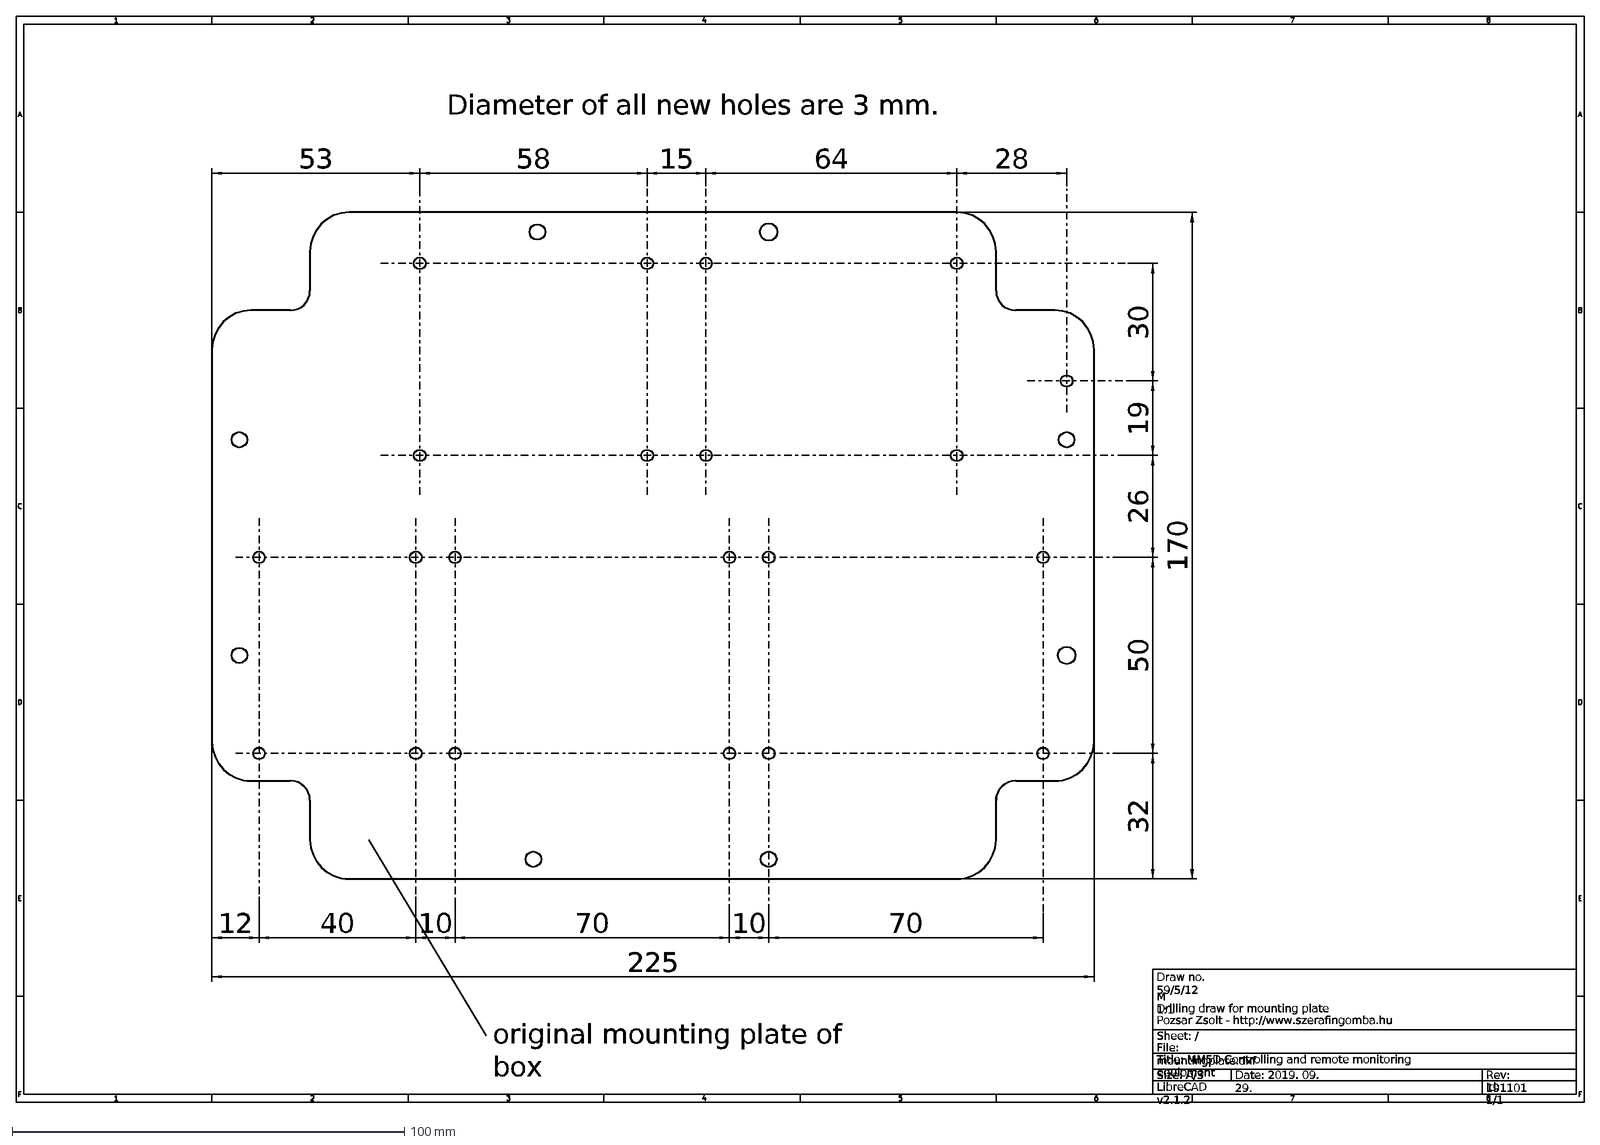
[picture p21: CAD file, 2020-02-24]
cad_files/drilling/mountingplate.dxf
32
50
12
40
10
70
225
26
19
30
170
53
58
15
64
28
Diameter of all new holes are 3 mm.
original mounting plate of box
LibreCAD v2.1.2
Sheet: /
Date: 2019. 09. 29.
Rev: 191101
Id: 1/1
Pozsar Zsolt - http://www.szerafingomba.hu
Title: MM5D Controlling and remote monitoring equipment
M 1:1
Draw no. 59/5/12
Drilling draw for mounting plate
File: mountingplate.dxf
Size: A/3

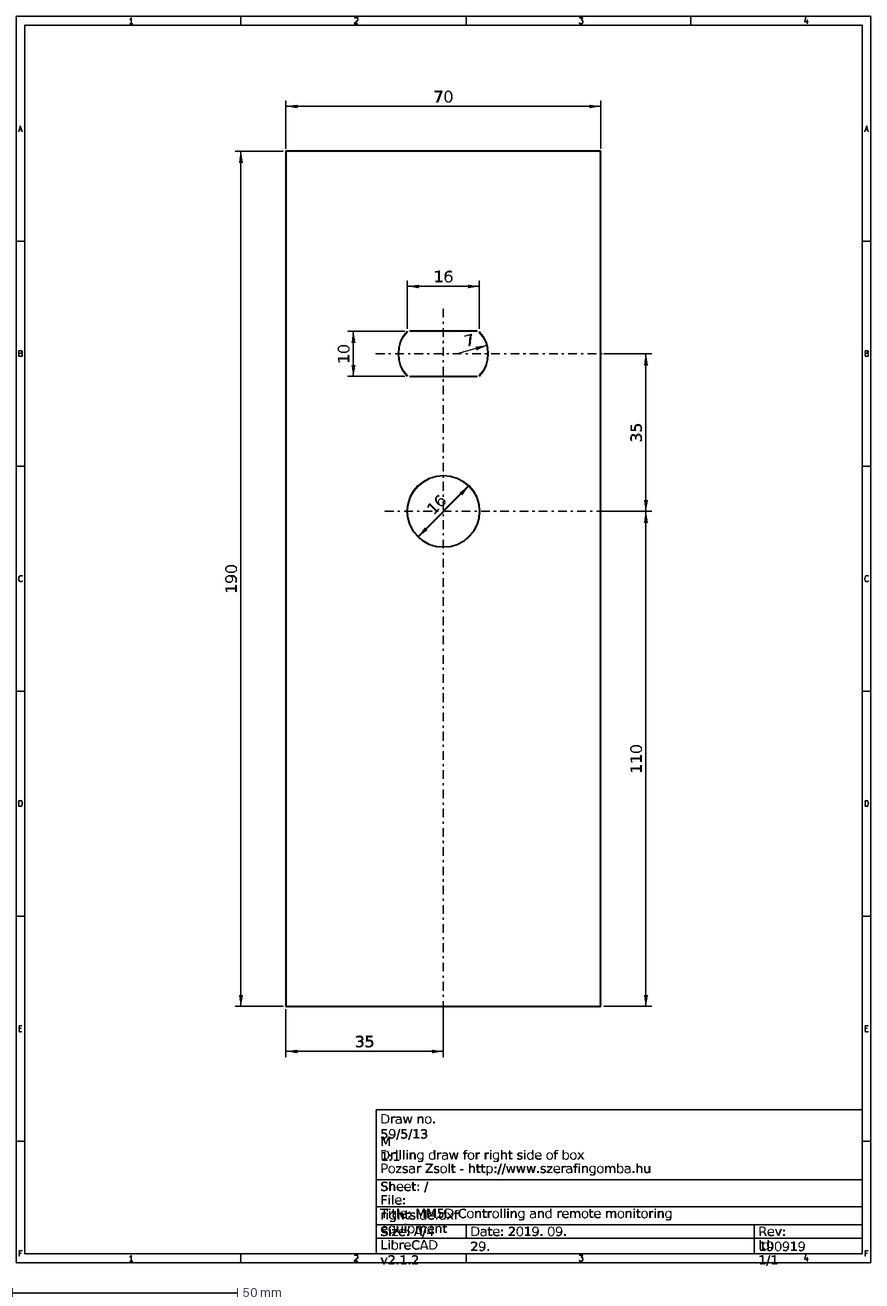
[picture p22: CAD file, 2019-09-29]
cad_files/drilling/rightside.dxf
16
7
10
110
35
190
70
Size: A/4
LibreCAD v2.1.2
Sheet: /
Date: 2019. 09. 29.
Rev: 190919
Id: 1/1
Pozsar Zsolt - http://www.szerafingomba.hu
Title: MM5D Controlling and remote monitoring equipment
M 1:1
Draw no. 59/5/13
Drilling draw for right side of box
File: rightside.dxf

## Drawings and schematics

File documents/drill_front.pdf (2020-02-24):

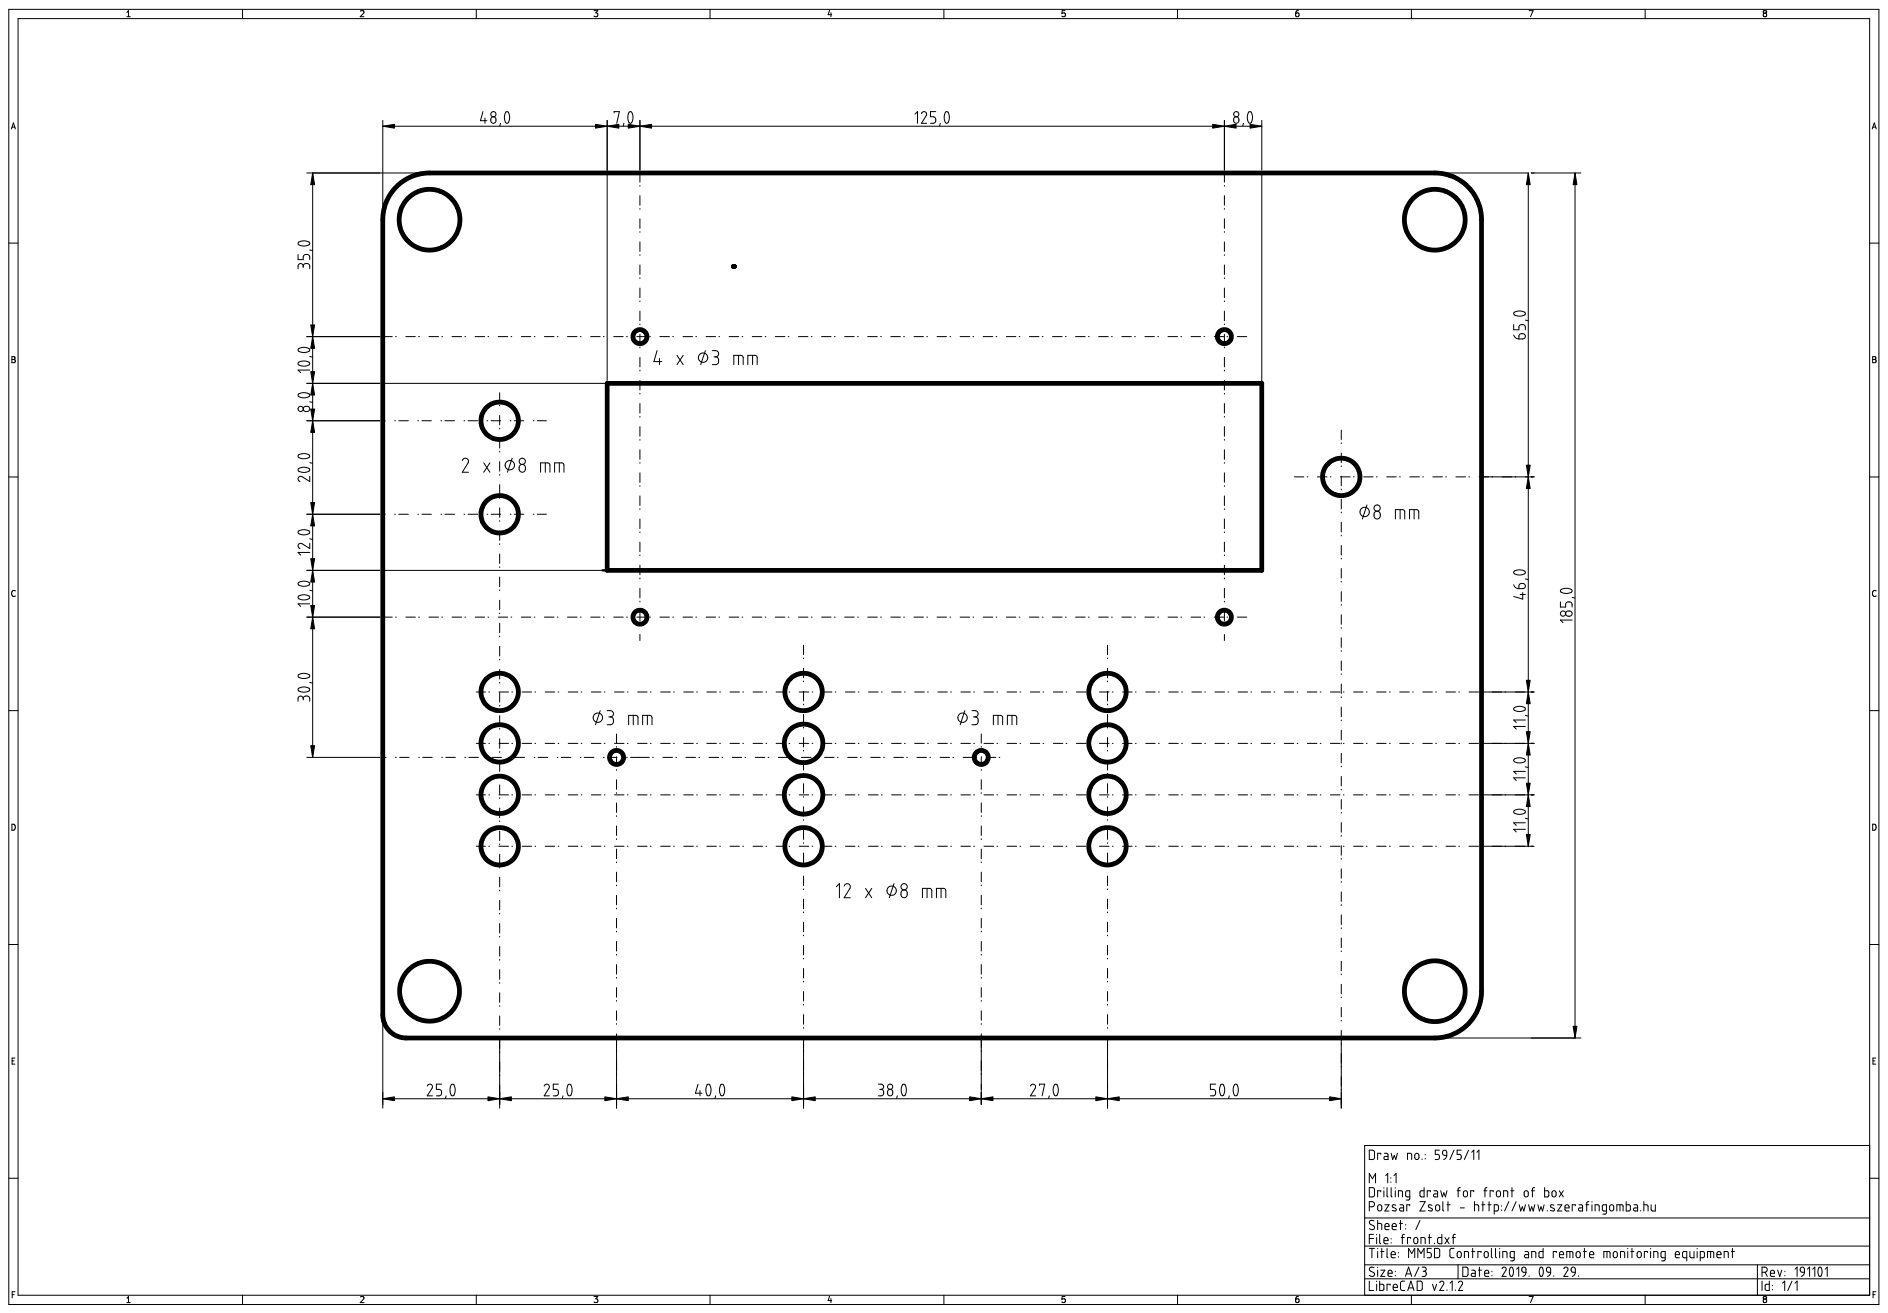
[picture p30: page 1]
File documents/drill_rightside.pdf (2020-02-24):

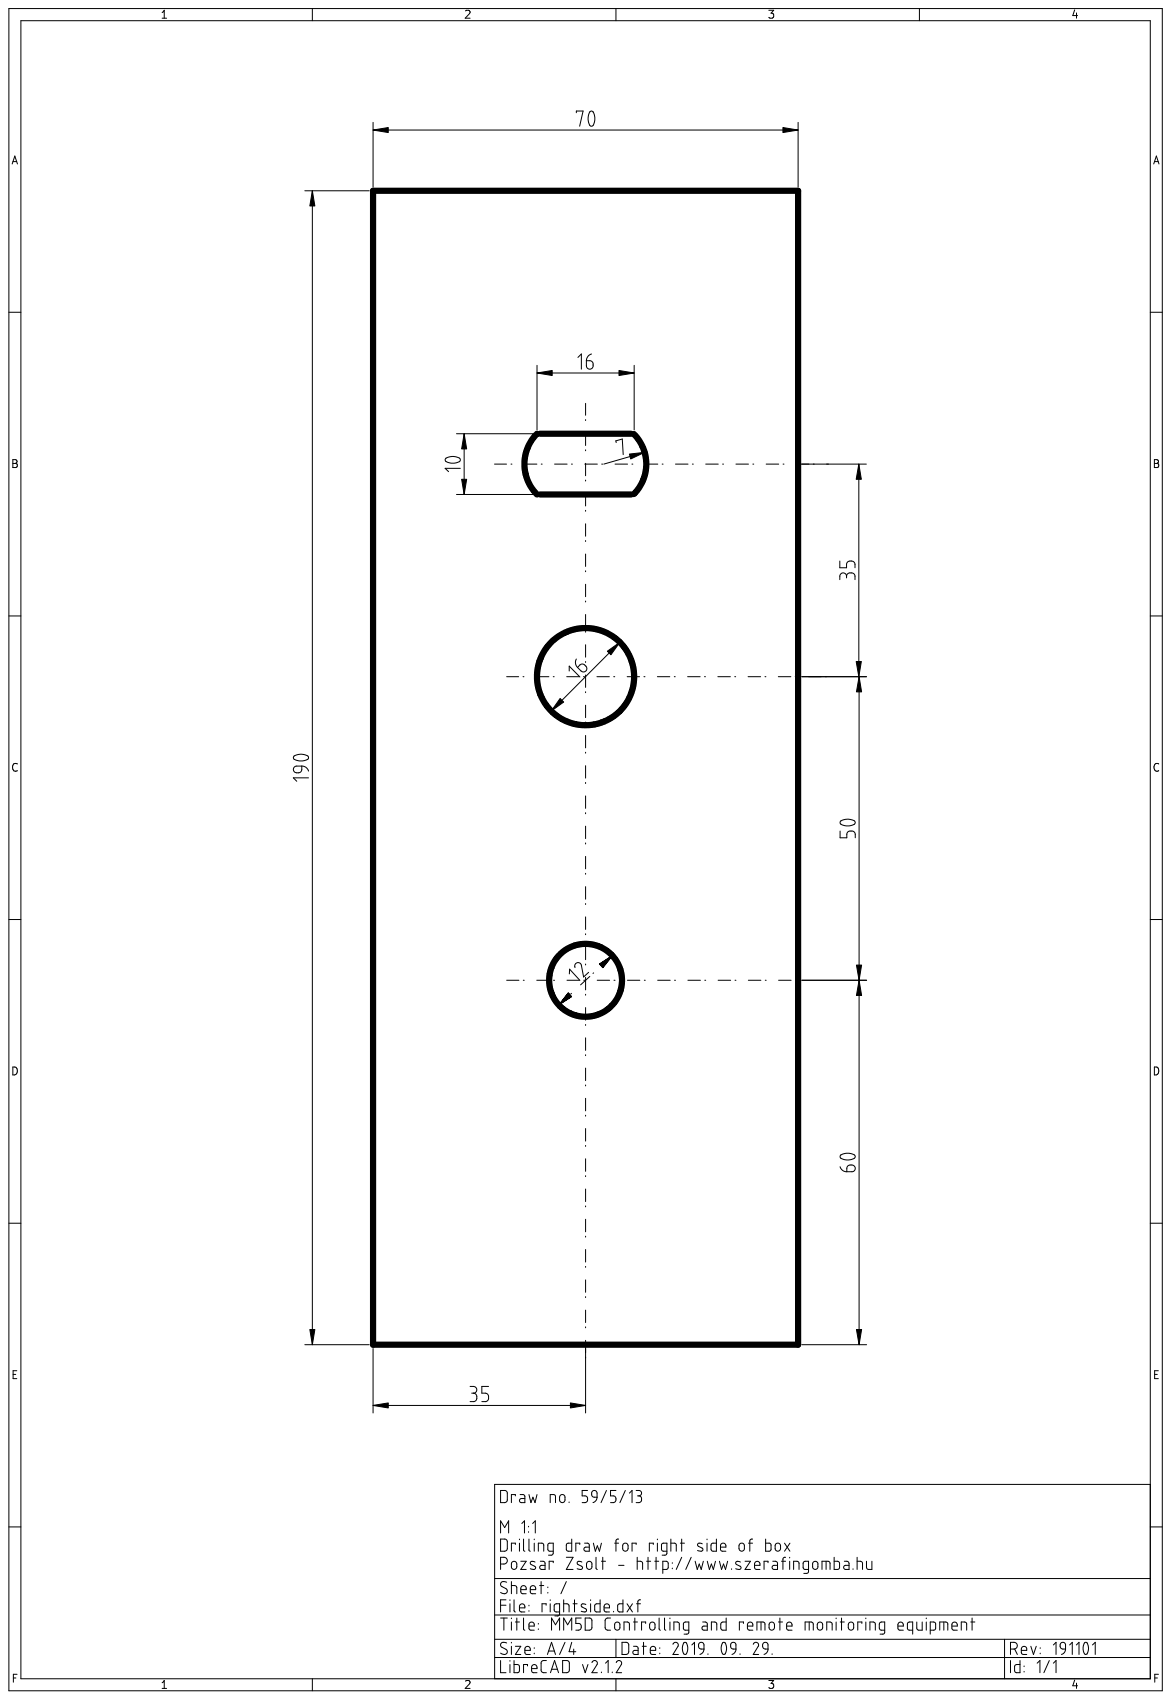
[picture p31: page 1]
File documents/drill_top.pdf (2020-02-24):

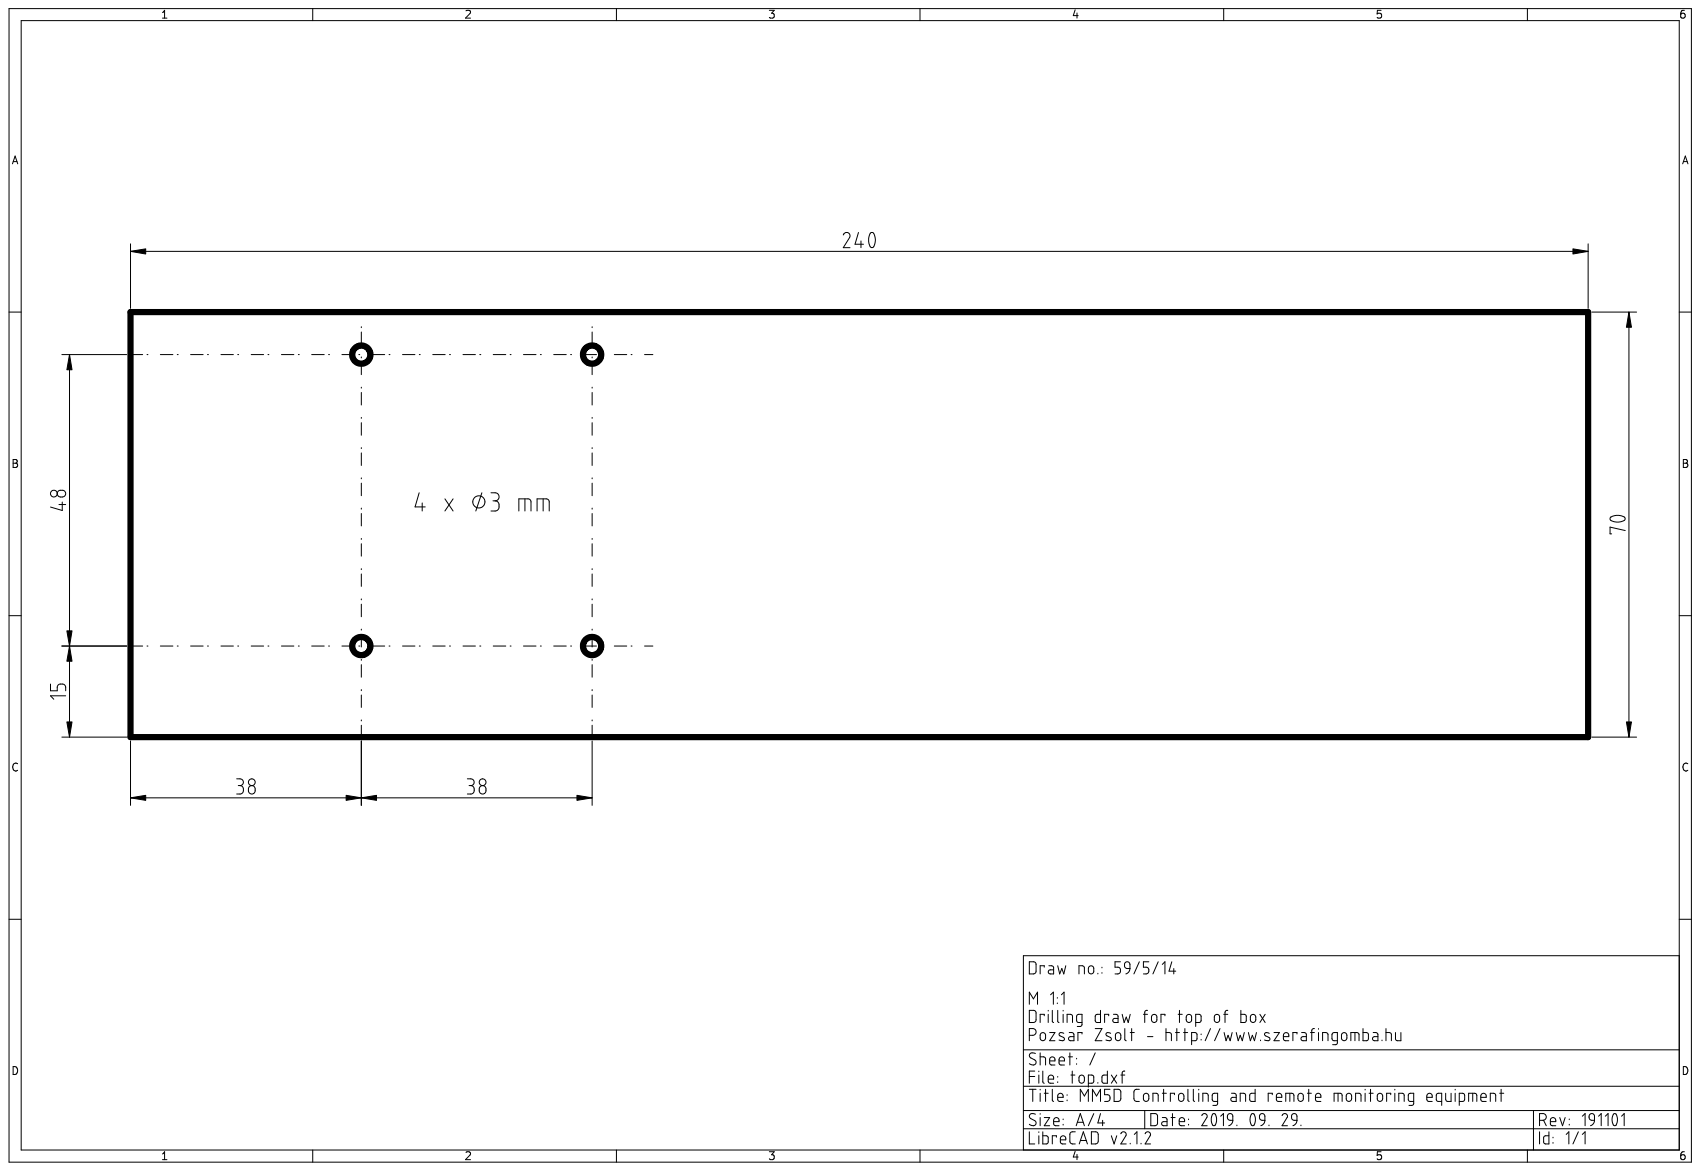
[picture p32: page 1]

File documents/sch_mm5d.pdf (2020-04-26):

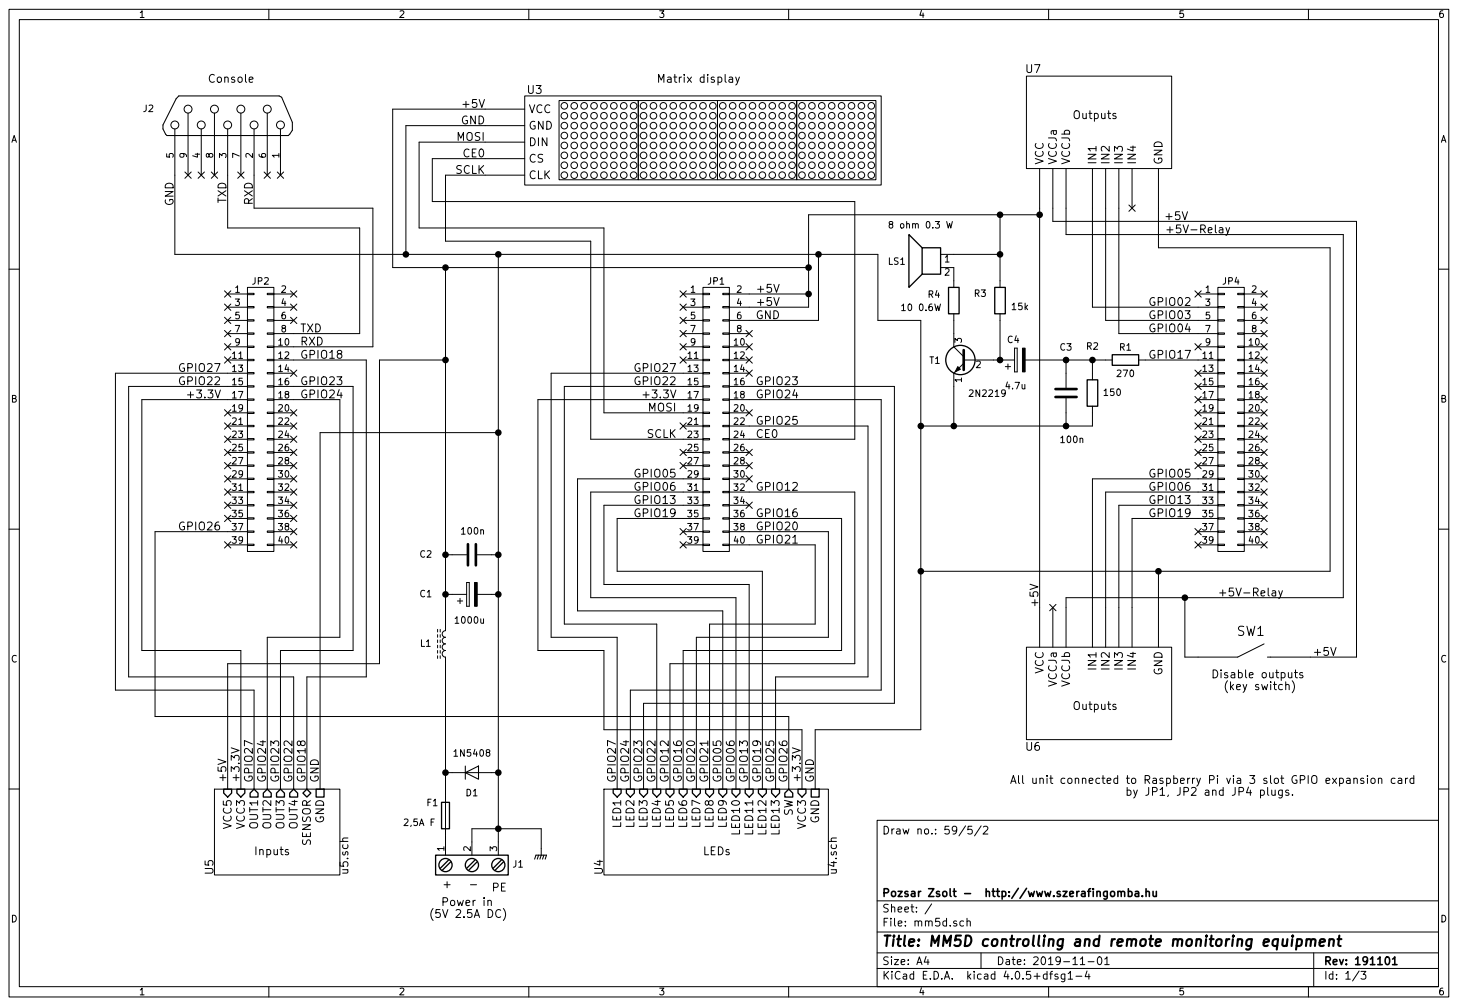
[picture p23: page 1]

Outputs

CE0
SCLK

All unit connected to Raspberry Pi via 3 slot GPIO expansion card

Id: 1/3 Title: MM5D controlling and remote monitoring equipment File: mm5d.sch Sheet: / Pozsar Zsolt - http://www.szerafingomba.hu Draw no.: 59/5/2

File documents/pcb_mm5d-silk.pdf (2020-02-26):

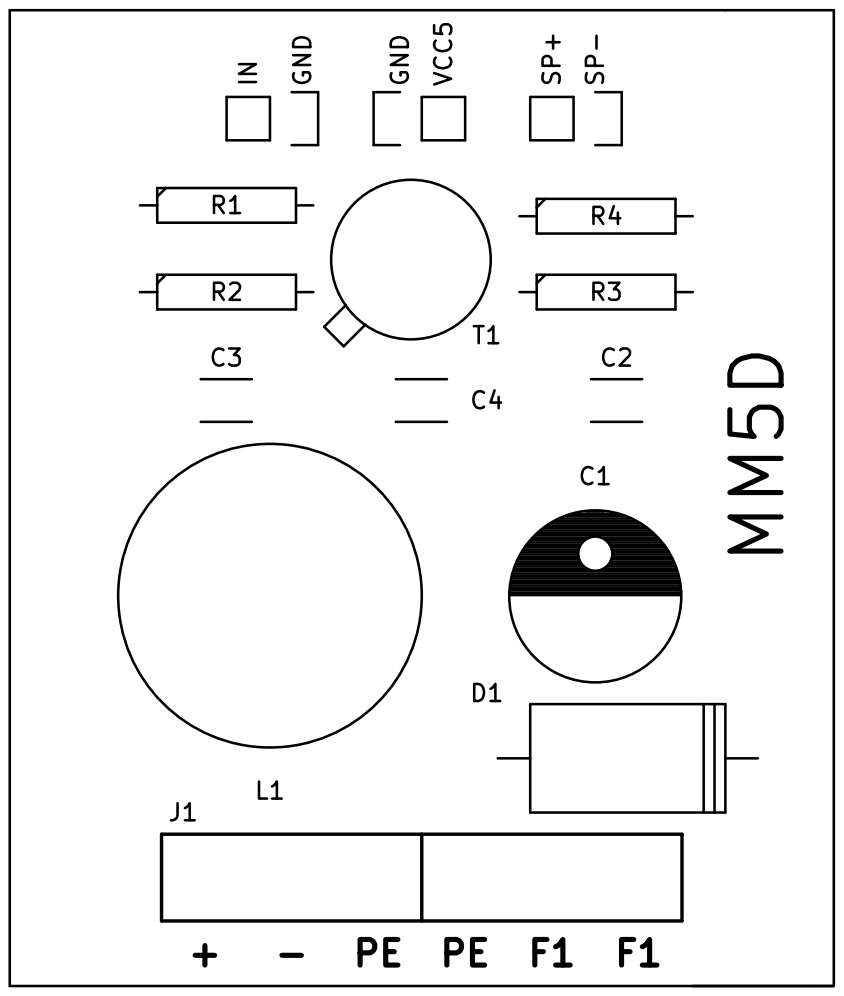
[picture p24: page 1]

File: mm5d.kicad_pcb Sheet: Pozsar Zsolt - http://www.szerafingomba.hu Draw no.: 59/5/6 MM5D

Id: 1/1 Title: MM5D controlling and remote monitoring equipment

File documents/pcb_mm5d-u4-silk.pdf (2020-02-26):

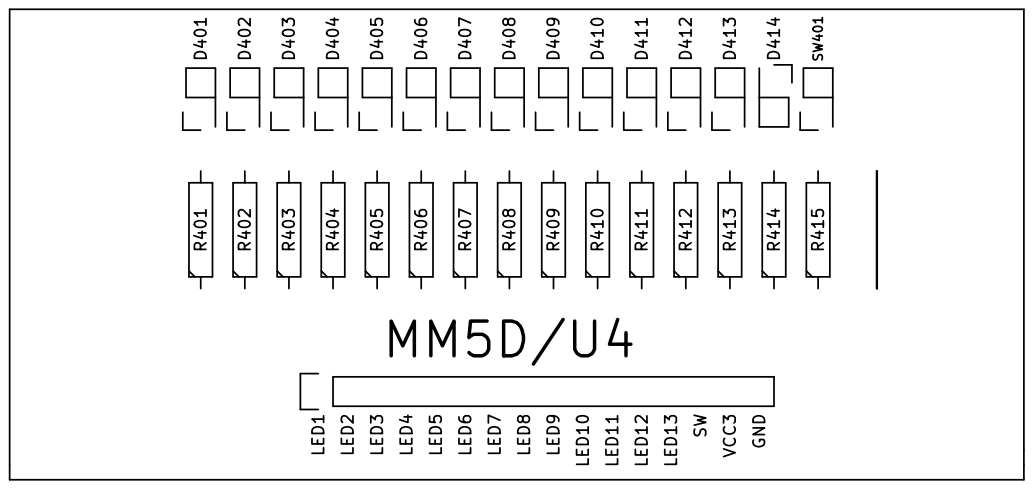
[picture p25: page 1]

File: u4.kicad_pcb Sheet: Pozsar Zsolt - http://www.szerafingomba.hu Unit U4

Id: 1/1 Title: MM5D controlling and remote monitoring equipment

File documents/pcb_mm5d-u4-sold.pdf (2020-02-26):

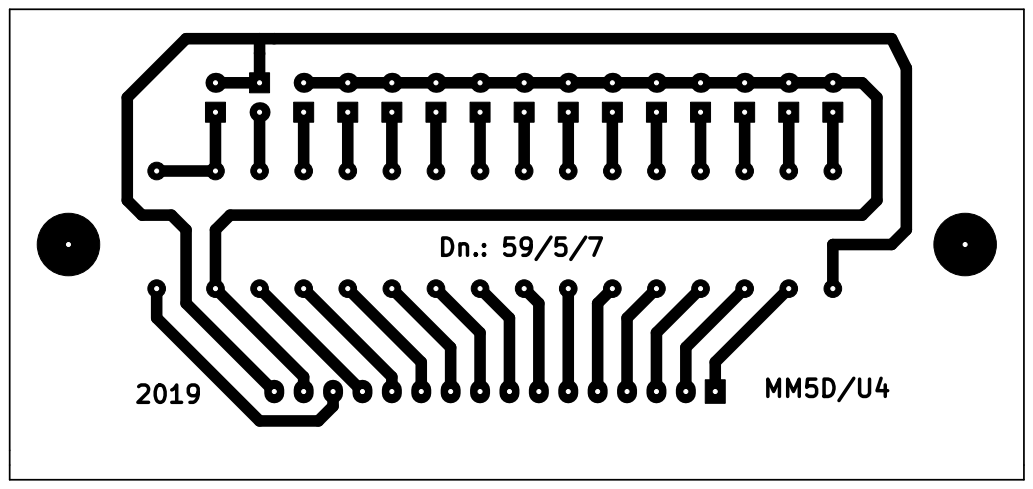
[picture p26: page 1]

LEDs Draw no.: 59/5/7 Dn.: 59/5/7

File: u4.kicad_pcb Sheet: Pozsar Zsolt - http://www.szerafingomba.hu Unit U4

Id: 1/1 Title: MM5D controlling and remote monitoring equipment

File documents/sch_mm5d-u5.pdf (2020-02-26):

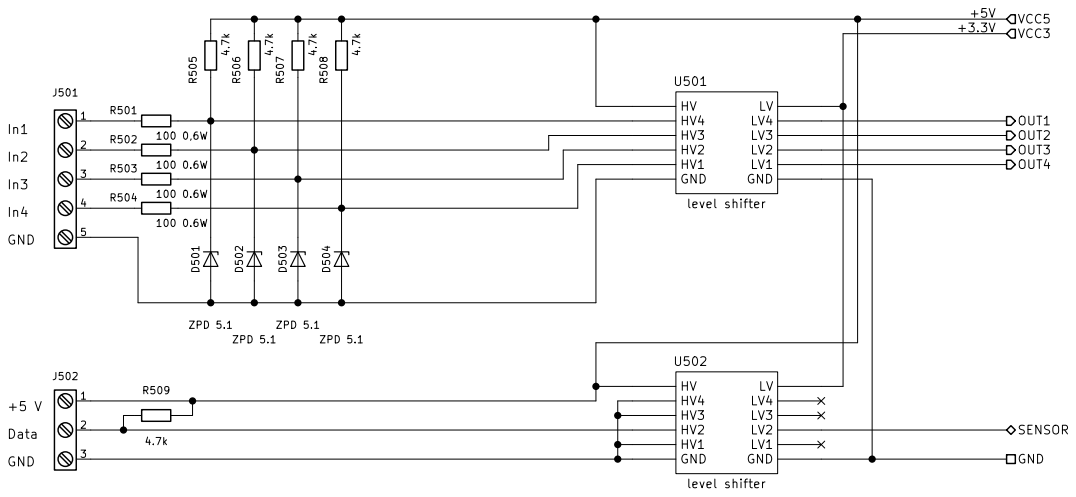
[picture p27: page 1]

+3.3V D501 ZPD 5.1 D502 ZPD 5.1 D503 ZPD 5.1 D504 ZPD 5.1

Id: 2/3 Title: MM5D controlling and remote monitoring equipment File: u5.sch Sheet: /U5/ Pozsar Zsolt - http://www.szerafingomba.hu Module U5

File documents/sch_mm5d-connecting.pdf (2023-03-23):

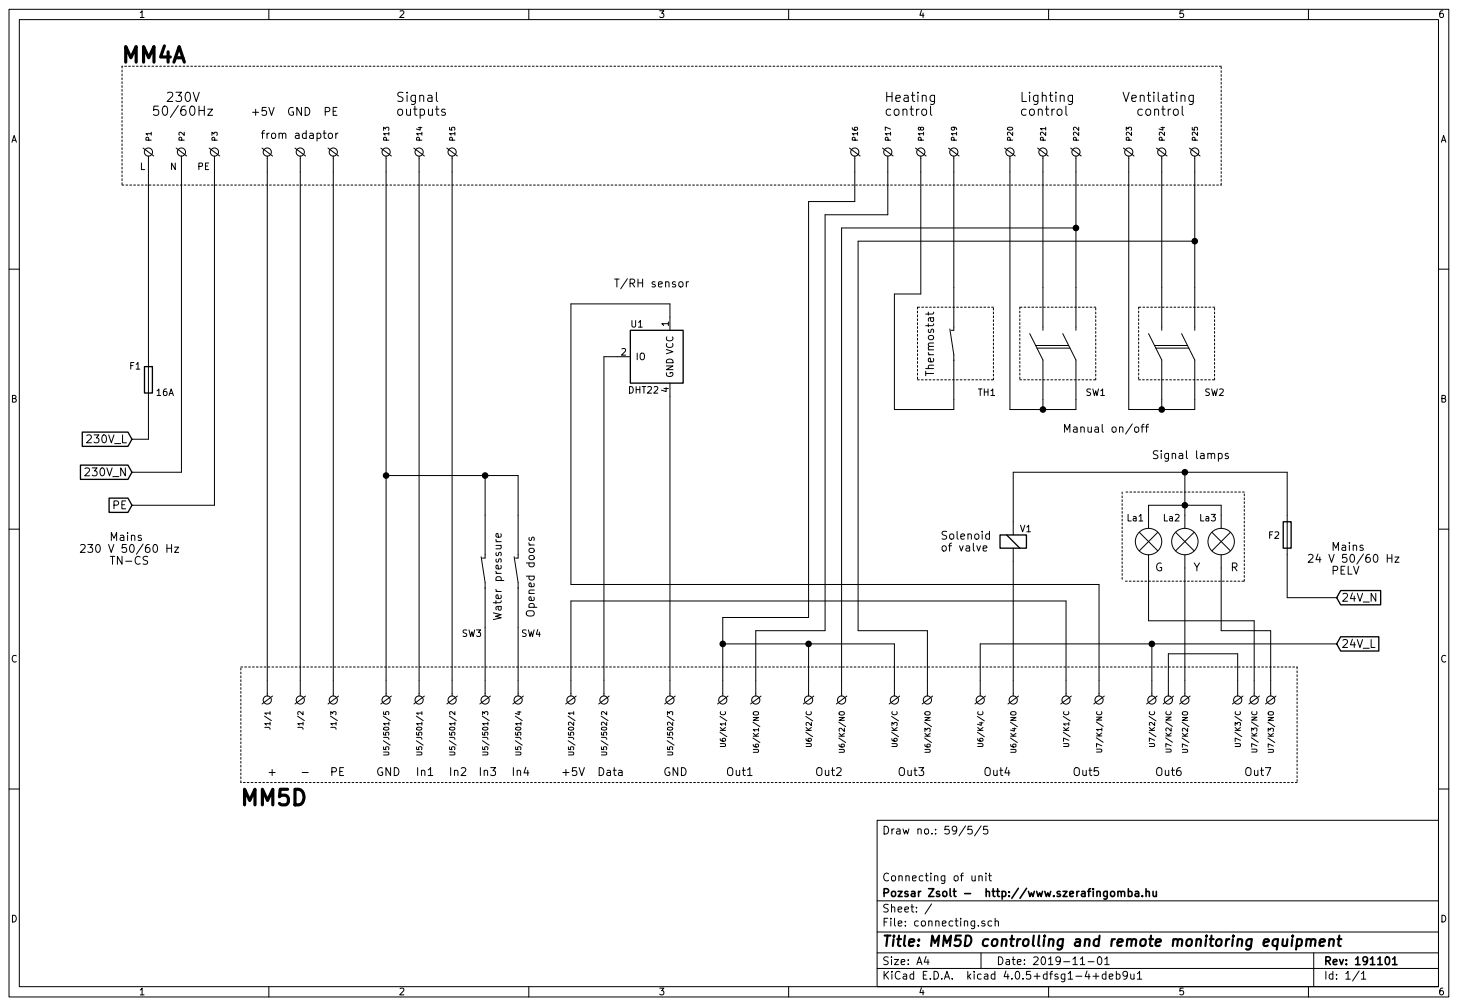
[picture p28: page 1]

File: connecting.sch Sheet: / Pozsar Zsolt - http://www.szerafingomba.hu

Id: 1/1 Title: MM5D controlling and remote monitoring equipment

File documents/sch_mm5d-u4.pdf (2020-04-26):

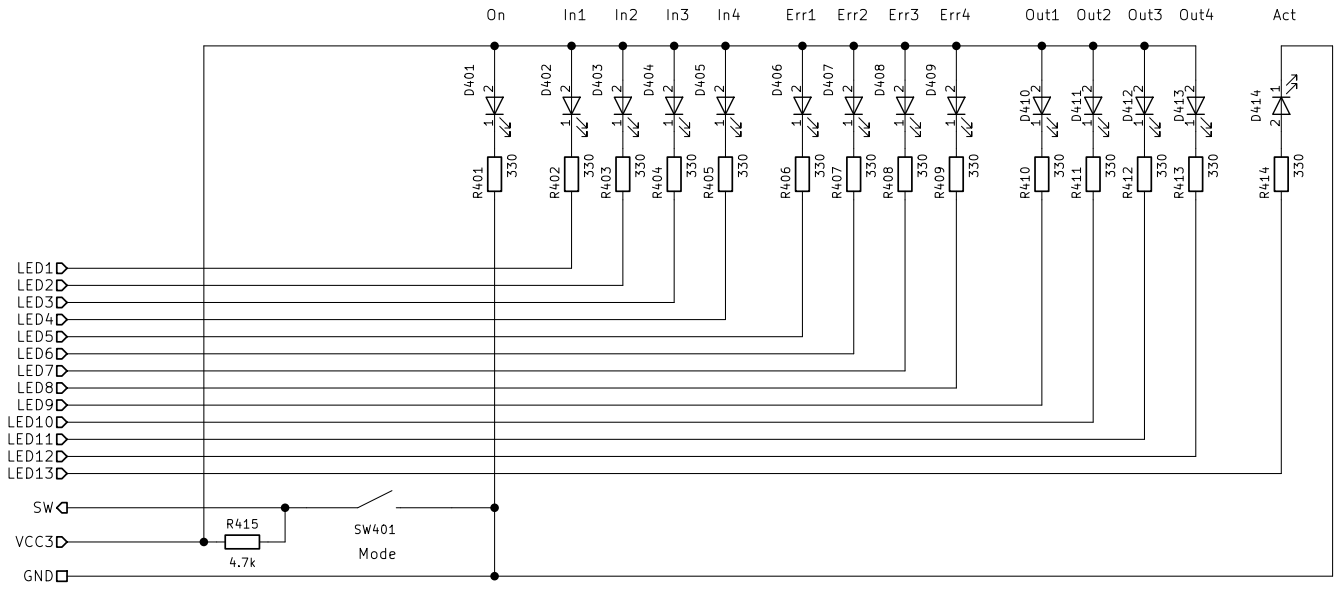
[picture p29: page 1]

Id: 3/3 Title: MM5D controlling and remote monitoring equipment File: u4.sch Sheet: /U4/ Pozsar Zsolt - http://www.szerafingomba.hu Module U4
